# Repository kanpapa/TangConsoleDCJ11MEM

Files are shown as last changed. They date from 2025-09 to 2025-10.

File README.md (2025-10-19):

# TangConsoleDCJ11MEM
DEC DCJ11 processor test board using memory systems and peripherals implemented  on Tang Console 138K.

This document is written mostly in Japanese. If necessary, please use a translation service such as DeepL or Google.

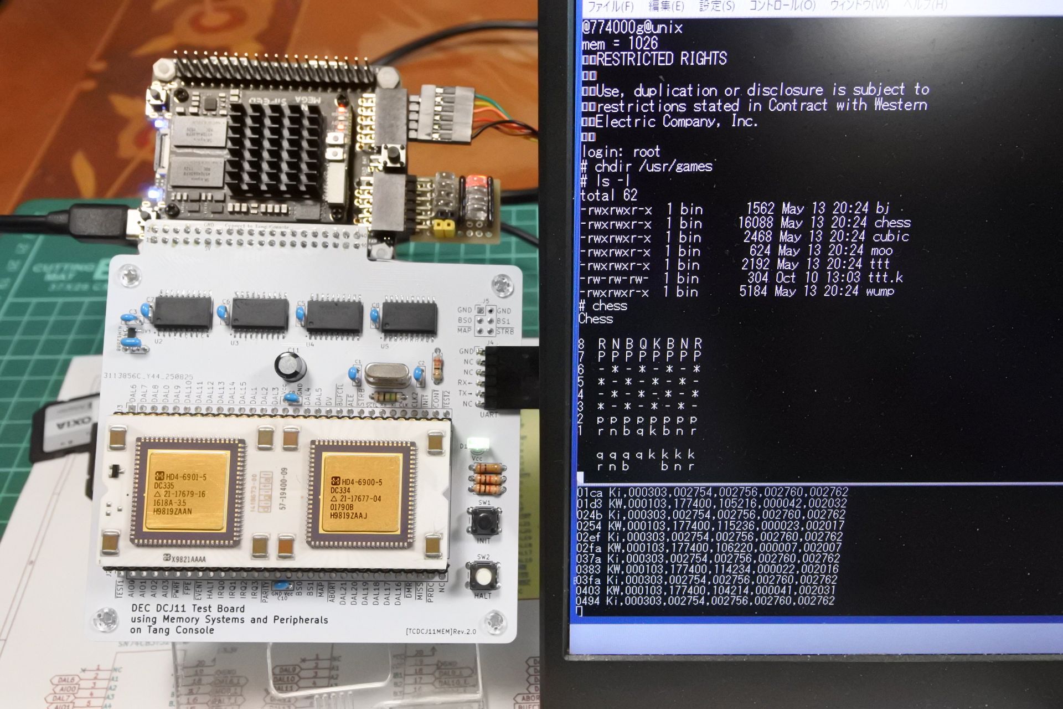
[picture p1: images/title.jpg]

# 概要
- PDP-11の命令セットを持つCPU「DEC DCJ11」のメモリシステムと周辺装置をFPGAボード(Tang Console 138K)上に実装する試みです．
- TangNano20Kを用いた同様のプロジェクト[TangNanoDCJ11MEM](https://github.com/ryomuk/TangNanoDCJ11MEM)の続編です．

各種説明は[doc/](./doc/)にあるファイルに記載しています．

## 最近の話題
- 以前の話題は[更新ログ](doc/01_updatelog.md)参照
- 2025/10/17
  - 磁気テープリーダ(TM11)等を実装してunix v7や2.9BSDをインストール可能なバージョン(20251017)を公開しました．わりと大幅なアップデートです．
  - ブートローダーのアドレスを実物のROM(BM873-YA)に準拠させるように変更しました．主なアドレスは下記のようになっています．詳細は[doc/06-1-bootloader.md](doc/06-1_bootloader.md)を参照して下さい．
    - RK(unix v1): 773700
    - RP(unix v6, RT-11等): 773010
  - 説明文書を[doc/](./doc/)にまとめました．まだログファイルそのままだったりソースのコメントのコピペばかりですが，動かすのに必要な情報は揃っていると思います．気が向いたらもう少し書き直します．

## 主要なファイル一覧
```
.
├── diskimage : SDメモリ用データ
│   ├── Caldera-license.pdf : UNIXのライセンス条項
│   ├── sd-unix-v1.dsk      : unix v1用disk image
│   └── sd-unix-v6.dsk      : unix v6用disk image
├── doc                      : 説明用文書
│   ├── 01_updatelog.md
│   ├── 02_PCB.md
│   ├── 03_FPGA.md
│   ├── 04_Interface.md
│   ├── 05_SDmemory.md
│   ├── 06-0_applications.md
│   ├── 06-1_bootloader.md
│   ├── 06-2_papertapebasic.md
│   ├── 06-3_unix-v1.md
│   ├── 06-4_unix-v6.md
│   ├── 06-5_unix-v7.md
│   ├── 06_6_unix-2.9BSD.md
│   ├── 06_7_RT-11v4.md
│   ├── 07_debugtool
│   └── 08_references.md
├── hdl                      : Gowin EDA用プロジェクト
│   ├── old                 : 旧版のバックアップ(あれば)
│   └── TangConsoleDCJ11MEM_project.xxxxxxxx
│       └── src
│             ├── rom.v      : ブートローダー
│             ├── sdhd.v     : HDエミュレータモジュール
│             ├── sdtape.v   : 紙テープエミュレータモジュール
│             ├── tc138k.cst : 物理制約(ピンアサイン)
│             ├── top.v      : メインプログラム
│             ├── uart.v     : uartモジュール
│             └── ws2812.v   : WS2812モジュール
├── images                    : 文書用画像ファイル
├── pcb
│   └── rev2.0 : 回路図，基板データ等(KiCAD 8用)
└── README.md
```
- diskimageフォルダ内にあるSDメモリ用のイメージファイルはUNIXのオリジナルソースからの派生物なので，ライセンス条件は Caldera-license.pdf (昔のBSD?)に従います．
- その他の部分についてはMITライセンスです．

## 動作状況
- unix v1
  - multi userで起動，rootでログインできました．
  - edでASCIIARTのプログラムを書いてccでセルフコンパイルして実行できました．
- unix v6
  - multi userで起動，rootでログインできました．
  - /usr/games/ にあるchessやbj, tttなどが動きました．
  - 実機でカーネルの再構築ができました．
- paper tape
  - paper tape BASICが起動して簡単なプログラムが動作しました．
  - unix v1, unix v6のデバイスとして読むことができました．
- rt-11 v4
  - 起動してHELP, DIRが動きました．(top.vのオプションを変更してビルドする必要あり)
- unix v7  
  - ディストリビューションテープからインストールとブートができました．
- 2.9BSD
  - ディストリビューションテープからインストールとブートができました．
  
## 既知の問題
- まれに(電源投入直後が多い)v6のブート時にpanicになって止まることがあります．
Tang Console のreconfigボタン(pmodコネクタのあたりにあるやつ)を押してリセットしてからリトライすると直ることが多いです．
- v6のファイルシステムは壊れやすいような気がします．電源断前にはsync3〜4回のおまじないが必要かも．
- v7でハードディスクにddしたbootloaderがちゃんと動かないような気がします．tapeのブートローダーでブートできます．

## 開発環境
- Windows 11
  - KiCAD 8.0.5
  - GOWIN FPGA Designer V1.9.11.02(64-bit)
  - VMware Workstation 17 Player
    - Ubuntu 22.04.4
      - dd
      - simh
  - TeraTerm
  - PDP11GUI

# 動画
- [UNIX V6 on DEC DCJ-11 (PDP-11) with Tang Console 138K](https://www.youtube.com/watch?v=6rK0t8tJp9Y)

# 更新履歴
- 2025/09/03: 初版(20250922)公開
- 2025/09/06: unix v6でもccが動いたのでREADME修正．
- 2025/09/08: READMEに軽微な情報追加．
- 2025/09/22: 20250922版(pmod paper tape実装)暫定公開．(説明は未)
- 2025/09/26: 20250926版公開．(RT-11 v4起動)
- 2025/10/19: 20251017版公開．(磁気テープ実装, unix v7, 2.9BSD起動)
- 2025/10/19: ドキュメント構成見直し

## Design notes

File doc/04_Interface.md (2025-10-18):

# インターフェース
## Pmodコネクタ
- Tang ConsoleのPmod(上がPmod1, 下がPmod0)のピンアサインは下記の通りです。
```
Pmod1:
+-----+-----+--------+--------+--------+--------+
| 3V3 | GND |LED_RGB |   NC   |   NC   |   NC   |
+-----+-----+--------+--------+--------+--------+
| 3V3 | GND |   NC   |   NC   |   NC   | LOG_TX |
+-----+-----+--------+--------+--------+--------+
Pmod0:
+-----+-----+---------+---------+---------+---------+
| 3V3 | GND |  CLK    |MISO(D0) |MOSI(CMD)| ~CS(D3) |
+-----+-----+---------+---------+---------+---------+
| 3V3 | GND |   NC    |  ~DET   | NC(D2)  |  NC(D1) |
+-----+-----+---------+---------+---------+---------+
```
### Pmod1(LED_RBG)
- WS2812 LED array用の信号を出力しています．デバッグをするにあたりかなり役に立っています．見た目も格好いいのでお薦めです．
- 基本情報8個、詳細情報16個+16個、計40個のLEDアレイへの出力です。
- 8個のアレイを継げれば基本情報8個だけ表示します。
- 表示内容はtop.vを参照して下さい。

### Pmod1(LOG_TX)
- ディスクアクセス等の情報を出力しています．

### Pmod0
  - テープデバイス(PC, TM)をエミュレートするためのSDカードを搭載します．Digilentのピンアサイン準拠になっています．SipeedのSDカードインターフェースもv2であれば同じようです．

## SW1, SW2
Tang Consoleのオンボードスイッチ(SW1, SW2)
- SW1: LEDアレイの出力内容切り替え．詳細はtop.v参照．
- SW2: 今のところ(20251017)明確な用途では使用していません．下記の用途で使うことがありますが，バージョンによって異なります．
  - sdtape.vの書き込みバッファのフラッシュ
  - 磁気テープのEOFフラグ
- SW1, SW2同時押し: SDメモリモジュール，UARTのリセット
  - Reconfigボタンでリセットの方を使うのであまり使っていません．

## ターミナルソフト(TeraTerm, PDP11GUI)との接続
- TTY入出力はTangConsoleのUSB(JTAGと共用)とCPU基板のUARTの2箇所に同じものが出ています．当初USBが不安定だったのでそのようにしたのですが，今はわりと安定してきたのでUSBだけでOKです．(両方使うとTeraTermとPDP11GUIを同時に接続できます．)
- TeraTermの設定
  - 基本的には115200bps,8N1N．ただし，UNIX V6だと7bit, parity=spaceにする必要あり．
  - 改行コードは入力出力ともCR
  - 送信遅延 10ms/字, 100ms/行
- CPU基板のUARTは，TXは3.3V出力(5VTTLで受信可)，RXは5V耐性なので，USBシリアル変換ケーブルは3.3V用，5V用のどちらでもOKです．

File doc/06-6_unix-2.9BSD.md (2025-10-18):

# 2.9BSD
- CPUタイプが70と認識されるのですが、それだとbootしてくれませんでした。CPUタイプを40とすればbootしたのでそれで対処しました。
## ディストリビューションテープからのインストール
- [https://www.tuhs.org/Archive/Distributions/UCB/2.9BSD/](https://www.tuhs.org/Archive/Distributions/UCB/2.9BSD/)にあるfile?.gz と usr.tar.gz をgunzipして，下記の配置でsdメモリに書き込み，PmodのSDメモリに搭載します．
```
dd if=file1 of=29bsdtape.dsk
dd if=file2 of=29bsdtape.dsk seek=65536 conv=notrunc
dd if=file3 of=29bsdtape.dsk seek=131072 conv=notrunc
dd if=file4 of=29bsdtape.dsk seek=196608 conv=notrunc
dd if=file5 of=29bsdtape.dsk seek=262144 conv=notrunc
dd if=file6 of=29bsdtape.dsk seek=327680 conv=notrunc
dd if=file7 of=29bsdtape.dsk seek=393216 conv=notrunc
dd if=usr.tar of=29bsdtape.dsk seek=458752 conv=notrunc

dd if=29bsdtape.dsk of=/dev/xxx
```
- Tang Consoleには空のSDメモリ(HDD用)を搭載します．
- https://www.tuhs.org/Archive/Distributions/UCB/Documentation/2.9bsd_setup.html の手順に従ってインストールします．
- 100040gで777570(switch register)に40を書き込みます。(ODTで手動で書き込んでもOK。)
- rom.vにより，100000番地以降にテープ用のブートローダーが書かれているのでODTで100000gで0番地に読み込まれます．これを0gで実行します．
```
@100040g
100050
@777570/000040 
@100000g
100014
@0
40Boot
: tm(0,3)
Mkfs
file system: rp(0,0)
file sys size: 5200
interleaving factor (m; 5 default): 
interleaving modulus (n; 10 default): 
isize = 3328
m/n = 5 10
Exit called

40Boot
: tm(0,4)
Restor
Tape? tm(0,6)
Disk? rp(0,0)
Last chance before scribbling on disk. 
End of tape
*** 数分かかる ***
40Boot
: rp(0,0)rpunix

Berkeley UNIX (Rev. 2.9.1) Sun Nov 20 14:55:50 PST 1983
mem = 135872

CONFIGURE SYSTEM:
xp ? csr 176700 vector 254 interrupt vector already in use
rk 0 csr 177400 vector 220 attached
hk ? csr 177440 vector 210 didn't interrupt
rl ? csr 174400 vector 160 didn't interrupt
rp ? csr 176700 vector 254 didn't interrupt
ht 0 csr 172440 vector 224 skipped:  No CSR
tm 0 csr 172520 vector 224 attached
ts 0 csr 172520 vector 224 interrupt vector already in use
dh ? csr 160020 vector 370 skipped:  No CSR
dm ? csr 170500 vector 360 skipped:  No autoconfig routines
dz ? csr 160110 vector 320 didn't interrupt
dz ? csr 160110 vector 320 didn't interrupt
dn 0 csr 175200 vector 300 skipped:  No autoconfig routines
vp ? csr 177500 vector 174 skipped:  No autoconfig routines
lp ? csr 177514 vector 200 didn't interrupt
Erase=^?, kill=^U, intr=^C
# dd if=/mdec/rpuboot of=/dev/rrp0a count=1
0+1 records in
0+1 records out
# cd /dev
# ./MAKE tm0
# ./MAKE rp1a rp1b rp1c rp1h
# ls rp*
rp0a  rp0b  rp0c  rp0h  rp1a  rp1b  rp1c  rp1h
# ls rrp*
rrp0a  rrp0b  rrp0c  rrp0h  rrp1a  rrp1b  rrp1c  rrp1h
# /etc/mkfs /dev/rrp1h 41590
isize = 26608
m/n = 5 10
# fsck /dev/rp0a

/dev/rp0a
File System: /

** Checking /dev/rp0a
** Phase 1 - Check Blocks and Sizes
** Phase 2 - Check Pathnames
** Phase 3 - Check Connectivity
** Phase 4 - Check Reference Counts
** Phase 5 - Check Free List 
250 files 1916 blocks 3074 free
# fsck /dev/rp1h

/dev/rp1h
File System: 

NEED SCRATCH FILE (65 BLKS)
ENTER FILENAME:  hoge
** Checking /dev/rp1h
** Phase 1 - Check Blocks and Sizes
** Phase 2 - Check Pathnames
** Phase 3 - Check Connectivity
** Phase 4 - Check Reference Counts
** Phase 5 - Check Free List 
3 files 6 blocks 39919 free
# /etc/mount /dev/rp1h /usr
# cd /usr
# df .
Filesystem  Mounted on  kbytes    used    free  % used
/dev/rp1h   /usr         39925       6   39919      0%
# mt -t /dev/nrmt0 fsf 7
# tar xvpf /dev/rmt0
Tar: blocksize = 20
x ./70/adb, 28204 bytes, 56 tape blocks
x ./70/make, 18182 bytes, 36 tape blocks
x ./70/dump, 9806 bytes, 20 tape blocks

*** 1時間ぐらいかかる ***

x ./ingres/version, 92 bytes, 1 tape blocks
x ./ingres/.cshrc, 64 bytes, 1 tape blocks
x ./ingres/.login, 158 bytes, 1 tape blocks
x ./ingres/.exrc, 27 bytes, 1 tape blocks
# ls
70          dict        ingres      man         public      tmp
adm         doc         lib         msgs        spool       ucb
bin         games       local       net         src
contrib     include     lost+found  preserve    sys
# ls bin
512dumpdir  dc          look        prep        sh          uuencode
512restor   delrem      lookbib     prfile      spell       uulog
Mail        deroff      lorder      primes      split       uuname
ac          diff3       ls          printenv    struct      uusend
at          dumpdir     m4          prof        sum         uusnap
awk         egrep       mesg        ptx         sync        uustat
basename    enroll      mkdir       px          tabs        uux
bc          eqn         neqn        pxp         tbl         why
cal         f77         nohup       quot        tp          write
calendar    factor      nroff       ratfor      tr          xget
cb          find        ovadb       refer       troff       xsend
checkeq     join        pcc         remind      tsort       yacc
checkobj    learn       pi          restor      tty
col         lex         pix         rev         unifdef
comm        lint        plot        sa          uniq
crypt       login       pr          sed         uudecode
```

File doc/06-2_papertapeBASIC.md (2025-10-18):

# Paper Tape BASIC
- PmodのSDメモリを使ってPaper TapeBASICが起動できます．
  - Tang ConsoleのSDスロットではなく、PmodにSDメモリインターフェースを接続して使用します。
- SDメモリの先頭から0〜1GBを読み込み用，1GB〜2GBを書き込み用にしたので，SAVEコマンドも動かそうと思えば動かせます．(が、最新版のtop.vではSAVE後にSW2でバッファをフラッシュの機能が外されてるかもしれないので修正が必要です。)

## 使用方法

- [Paper Tape Archive](https://www.vaxhaven.com/Paper_Tape_Archive)から
absolute loader('ABSOLUTE-BINARY-LOADER.ptap')と，Paper Tape BASIC ('DEC-11-AJPB-PB.ptap')を入手し，sdメモリに書き込みます．(頭の000があると読めないようで，先頭の16byteを削除しました．)
- /dev/xxx は生のsdメモリの場所です．(先頭のブロックから書くので数字が付いてないやつ．'fdisk -l'等で調べて下さい．)
- 間違えるとパソコンの他のファイルシステムを破壊するので厳重に注意して行って下さい．

```
cat ABSOLUTE-BINARY-LOADER.ptap DEC-11-AJPB-PB.ptap | dd of=tapeimage.dat bs=1 skip=16
dd if=tapeimage.dat of=/dev/xxx
```
- PmodのSDメモリカードに入れて電源を入れ，ODT consoleから下記のように
してBASICが起動できます．

```
@157744g  ← bootstrap loaderを起動してabsolute loaderを読み込む
157500
@157500g  ← absolute loaderを起動してBASICを読み込む
PDP-11 BASIC, VERSION 007A
*O ?
DO YOU NEED THE EXTENDED FUNCTIONS?Y
HIGH-SPEED READER/PUNCH?N
SET UP THE EXTERNAL FUNCTION?N
MEMORY?56
READY
10 PRINT "HELLO WORLD"
LIST

10 PRINT "HELLO WORLD"
READY
RUN
HELLO WORLD

STOP AT LINE   10
READY
```

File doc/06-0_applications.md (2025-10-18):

# 応用例

## [ブートローダー](06-1_bootloader.md)
## [Paper Tape BASIC](06-2_papertapeBASIC.md)
## [Unix v1](06-3_unix-v1.md)
## [Unix v6](06-4_unix-v6.md)
## [Unix v7](06-5_unix-v7.md)
## [2.9BSD Unix](06-6_unix-2.9BSD.md)
## [RT-11 v4](06-7_RT-11v4.md)

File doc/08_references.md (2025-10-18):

# 関連情報
## データシート等
### bitsavers
- [DCJ11 Microprocessor User's Guide](http://www.bitsavers.org/pdf/dec/pdp11/1173/EK-DCJ11-UG-PRE_J11ug_Oct83.pdf), DEC, EK-DCJ11-UG-PRE(Preliminary)
- [Index of /pdf/dec/pdp11/j11](http://bitsavers.trailing-edge.com/pdf/dec/pdp11/j11/)
- [Index of /pdf/dec/pdp11/1173](http://bitsavers.trailing-edge.com/pdf/dec/pdp11/1173/)

## 先行事例，先駆者たち
- [PDP-11/HACK](http://madrona.ca/e/pdp11hack/index.html), Brent Hilpert
- [My PDP-11 Projects](https://www.5volts.ch/pages/pdp11hack/), Peter Schranz
- [PDP11 on a breadboard A.K.A. J11 Hack](https://www.chronworks.com/J11/), Len Bayles
- [S100 Bus PDP-11 CPU Board](http://www.s100computers.com/My%20System%20Pages/PDP11%20Board/PDP11%20Board.htm), John Monahan

## 開発環境関連
- [PDP-11(エミュ）上でCで"Hello, World!"](https://qiita.com/hifistar/items/8eff4a73087f3a41e19f), hifistar
- [PDP-11のgccクロスコンパイル環境の構築メモ](https://qiita.com/hifistar/items/187fd7ad780c6aa26141), hifistar
- [SimH (History Simulator)](http://simh.trailing-edge.com/)
- [j-hoppe/PDP11GUI](https://github.com/j-hoppe/PDP11GUI)

## Paper Tape Software関連
- [Paper Tape Archive](https://www.vaxhaven.com/Paper_Tape_Archive)
- [DEC PDP-11 Paper Tape Images](https://www.pcjs.org/software/dec/pdp11/tapes/)
- [PDP-11 Paper Tape BASIC](https://avitech.com.au/?page_id=709)
- [Learning PDP-11](https://www.learningpdp11.com/) Paper Tape BASICとboot loaderについてとても詳しく解説されています

## UNIX関連
- [The Unix Heritage Society](https://www.tuhs.org/)
- [V1](https://www.tuhs.org/cgi-bin/utree.pl?file=V1)
- [UNIX First Edition](https://gunkies.org/wiki/UNIX_First_Edition)
- [jserv/unix-v1](https://github.com/jserv/unix-v1)

## 関連記事
- [きょうのかんぱぱ](https://kanpapa.com/today/)
TangNanoDCJ11MEMを使って私がやっていないようなことまでやっていたり，ここのREADMEより詳しく解説されてたりします．
  - [TangNanoDCJ11MEMでPDP-11のCPUを動かしてみました 製作編](https://kanpapa.com/today/2024/07/pdp-11-dcj11-cpu-1.html), 
  - [TangNanoDCJ11MEMでPDP-11のCPUを動かしてみました bare metal編](https://kanpapa.com/today/2024/07/tangnanodcj11mem-pdp-11-cpu-2-bare-metal.html)
  - [TangNanoDCJ11MEMとPDP11GUIでPDP-11 BASICを動かしてみました](https://kanpapa.com/today/2024/08/tangnanodcj11mem-pdp-11-cpu-3-pdp11basic.html)
  - [PDP-11 DCJ11 CPUでUNIX v6を動かしてみました](https://kanpapa.com/today/2024/08/tangnanodcj11mem-pdp-11-cpu-4-unix-v6.html)
  - [PDP-11 DCJ11 CPUでMINI-UNIXを動かしてみました](https://kanpapa.com/today/2024/08/tangnanodcj11mem-pdp-11-dcj11-cpu-mini-unix.html)

## その他のDCJ-11関連のプロジェクト
- ushicow, [PDP-11 Card for Apple II の制作](https://note.com/ushicow/m/ma9f73d2251bc)
- VARIABITS LAB, [DCJ11](https://www.variabits.com/categories/dcj11/)

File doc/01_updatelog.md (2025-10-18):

# 更新ログ
- 2025/09/12
  - PmodにWS2812アレイを接続してアドレスやデータを表示させてみました．
- 2025/09/22
  - PmodのSDメモリに紙テープエミュレータを実装しました．tape BASICの実行や，unix v1, v6で読めます．
- 2025/09/25
  - RT-11 v4がブートできました．
- 2025/09/26
  - READMEにpmod端子，オンボードSWの説明を追加しました．

- top.vにある更新履歴のコメント
```
//---------------------------------------------------------------------------
// 2025/09/02: - Ported from Tang Nano 20K to Tang Console 138K
//             - Use CLK2 as a system clock
//             - Physical memory space extended from 16bit to 18bit
//
// 2025/09/07: - Some debug tool installed
// 2025/09/11: - WS2812 installed
// 2025/09/17: - Bugfix for using without SD memory
// 2025/09/19: - PC-11(Paper-Tape Reader/Punch) emulator implemented
//             - The punch function is disabled to prevent overwriting
//             - the SD card.
// 2025/09/22: - sw2_toggle and sw2_count installed for debug
// 2025/09/25: - Onboard sw's function changed
// 2025/09/26: - Invoke IRQ_ttyo at 60Hz (dirty workaround to boot RT-11)
// 2025/10/01: - Bugfix for disks
// 2025/10/02: - RP11 controller (with RP03) emulator implemented
// 2025/10/06: - TM11/TU10 magnetic tape emulator implemented
//             - Reset by GP (RESET instruction)  implemented
//             - Boot address changed (see rom.v)
// 2025/10/08: - Disk and magtape bugfix
// 2025/10/12: - SD_MEM_FRQ changed from 400kHz to 800kHz
//             - Make read MTSC1(772440) invoke bus error (for uv7 tape boot)
// 2025/10/13: - TM11: Space forward implemented
// 2025/10/14: - TM11: interrupt on 'write IE and no GO' implemented
// 2025/10/16: - Image size for RP03 changed (for 2.9BSD's sys/conf/ioconf.c)
//             - RT-11 causes MTSC1 buserror, so compile flag
//             - 'USE_RT11V4_WORKAROUND' added.
//             - '60Hz IRQ_ttyo' disabled, 'USE_RT11V4_WORKAROUND' enables it.
//             - Compile flag 'USE_MT_WRITE_PROTECT' to avoid overwrite tape
// 2025/10/17: - SD_MEM_FRQ changed from 800kHz to 1MHz
//---------------------------------------------------------------------------
```

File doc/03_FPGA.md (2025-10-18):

# ビルド時の注意点
## config
- Configurationのdual-purpose pinで，SSPI, READY, DONE, CPUをチェックします．
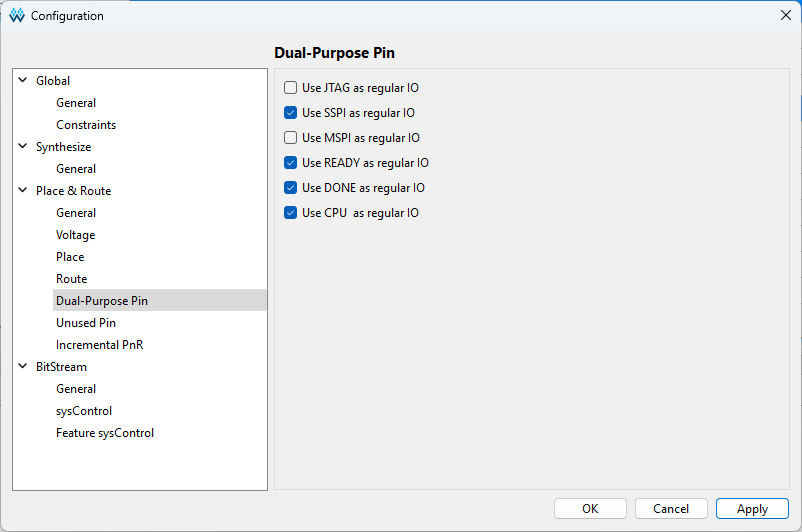
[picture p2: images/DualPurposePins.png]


## program
- UARTのポートが複数あるので，Gowin programmerでは適切なポートを選択する必要があります．
![ここに画像追加予定]()
- SRAMではなくflashメモリに書き込みます．数分かかります．
![ここに画像追加予定]()

## reconfigボタン
- Tang Consoleになって付いたreocnfigボタンがかなり便利です．FPGAをreconfigして初期化してくれます．Tang Nano 20Kのときには付いていなかった(それ用のパッドはある)ので毎回書き込み直していました．
![ここに画像追加予定]()

# FPGAに実装した機能
- コンソール入出力用UART
- Initialization Sequence時のPower-Up Configuration Register設定
- メモリ
  - 256KB RAM (760000-777777はI/O空間とROM用なので使えるのは248KB)
  - ブート用ROM
- ハードディスクドライブ RF11, RK11 (sdメモリによるエミュレーション)
- 外部演算装置 KE11-A (unix v1に必須)
- 紙テープリーダパンチャ PC11
- クロック KW11-L
- BS0, BS1は見ていません．DAL[15:0]とAIO[3:0]を見ればとりあえず十分だったので．
- DAL[21:18]も見ていません．
- 磁気テープドライブ TM11 (TU10)
- 大容量ハードディスクドライブRP11 (RP03)

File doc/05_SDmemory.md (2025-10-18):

## SDメモリ
- Tang Console本体のSDメモリスロットはHDDエミュレータ用です。
- PmodのSDカードインターフェース(ピン配置はDigilent仕様)のSDメモリは紙テープエミュレータと磁気テープエミュレータ用です。

## メモリイメージの構成
基本的にはtop.vのコメントに書いてあります．最新情報はソースを確認して下さい．
### ハードディスク
```
//---------------------------------------------------------------------------
// RF11 (drum), RK11 (disk), RP11 (with RP03 disk pack) controllers
// and TM11 (magtape)
// RF:  1024 block                             ( 512KB x 1)
// RK:  6144 block (=256cyl *  2sur *12sect)
//     (4872 block)(=203cyl *  2sur *12sect) (2.4 MB x 8)
// RP: 84000 block (=420cyl * 20tra *10sect)
//     (81200-83000 block) (=406-416cyl * 20tra *10sect) (40MB x 4)
// RP03's cylinder is 406, but 2.9BSD says 416.
//
// 1 block = 256word = 512B = 01000B
// SD memory block
//        0-  1023: RF  (00000000)
//     1024-  7167: RK0 (00002000)
//     7168- 13311: RK1 (00016000)
//    13312- 19455: RK2 (00032000)
//    19456- 25599: RK3 (00046000)
//    25600- 31742: RK4 (00062000)
//    31744- 37887: RK5 (00076000)
//    37888- 44031: RK6 (00112000)
//    44032- 50175: RK7 (00126000)
//    50176-134175: RP0 (00142000)
//   134176-218175: RP1 (00406040)
//   218176-302175: RP2 (00652100)
//   302176-386175: RP3 (01116140)
//
// # sample for making a sd image from unix disk drive images
// dd if=rf0 of=sd.dsk bs=512
// (if no rf0 file,  dd if=/dev/zero of=sd.dsk bs=512 count=1024)
// dd if=rk0 of=sd.dsk seek=1024  conv=notrunc
// dd if=rk1 of=sd.dsk seek=7168  conv=notrunc
// dd if=rk2 of=sd.dsk seek=13312 conv=notrunc
// dd if=rk3 of=sd.dsk seek=19456 conv=notrunc
// ...
// dd if=rp0 of=sd.dsk seek=50176 conv=notrunc
// ...
//---------------------------------------------------------------------------

### 磁気テープ
//--------------------------------------------------------------------------
// TM11
// maximum file block = 65536 block = 32MB
//      0-  65535: file0 (00000000)
//  65536- 131071: file1 (00200000)
// 131072- 196607: file2 (00400000)
// 196608- 262143: file3 (00600000)
// 262144- 327679: file4 (01000000)
// 327680- 393215: file5 (01200000)
// 393216- 458751: file6 (01400000)
// 458752- 524287: file7 (01600000)
// ...
// 983040-1048575: file15 (03600000)
//
// # sample for making a sd image from unix disk drive images
// dd if=file0 of=sdtape.dsk
// dd if=file1 of=sdtape.dsk seek=65536 conv=notrunc
// dd if=file2 of=sdtape.dsk seek=131072 conv=notrunc
// dd if=file3 of=sdtape.dsk seek=196608 conv=notrunc
// dd if=file4 of=sdtape.dsk seek=262144 conv=notrunc
// dd if=file5 of=sdtape.dsk seek=327680 conv=notrunc
// dd if=file6 of=sdtape.dsk seek=393216 conv=notrunc
// dd if=file7 of=sdtape.dsk seek=458752 conv=notrunc
// ...
// -----------------------------------------------------------------------
```
### 紙テープ
- 0〜1GBが読み込み用、1GB〜2GBが書き込み用ですが、書き込み機能はtop.vに修正が必要かも。

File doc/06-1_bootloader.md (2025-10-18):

# ブートローダー
- 773xxxのアドレスはBM873-YA restart/loader に準拠しています．
- 100000: TM11/TU10(磁気テープリーダ)
- 157744: 紙テープ用ブートストラップ
- 具体的なコードはrom.vを参照して下さい．

```
//---------------------------------------------------------------
// This ROM contains several boot programs
// - Magnetic Tape boot loader to install unix
// - Unix v1 boot ROM
// - BM873-YA restart/loader
// - Bootstrap Loader for paper tape
//
// Boot program entry addresses
//
// 100 000: TM11
// 157 744: PC11 (load absolute loader)
// 773 000: RF11 (not for unix v1, use 773700)
// 773 010: RK11 (unix v6, RT-11)
// 773 050: TM11
// 773 100: RP11
// 773 312: PC11
// 773 700: Unix V1 (RF)
//---------------------------------------------------------------

# スイッチレジスタ
//---------------------------------------------------------------
// SWR (Console Switches Register, 777570)
//---------------------------------------------------------------
REG_SWR = 'o173700; // UNIX V1 multi user mode
//REG_SWR = 'o073700; // UNIX V1 single user mode
//REG_SWR = 'o173030; // UNIX V6 single user mode
```
## 2.9BSD用の設定
2.9BSDは起動時にCPUタイプを自動判別しているようなのですが，'70'として判別されるとブートに失敗するので強制的に'40'にして起動しています．
詳細は https://www.tuhs.org/Archive/Distributions/UCB/Documentation/2.9bsd_setup.html を参照して下さい．

- CPUタイプを強制的に設定するためにSWRを使用します．
- Class: PDP11s
  - 40: 23, 34, 34A, 40, 60
  - 45: 45, 55
  - 70: 44, 70
- いちいち書くのは面倒なので，下記にレジスタ値を変更してHALTするプログラムを置きました．
  - 100040: SWR=o'000040
  - 100050: SWR=o'000045
  - 100070: SWR=o'000070

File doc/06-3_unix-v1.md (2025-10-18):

# UNIX V1
## 使用方法
### SDメモリの準備
- [jserv/unix-v1](https://github.com/jserv/unix-v1) にあるsimh用のunix-v1環境一式をmakeし， images/rf0.dsk, images/rk0.dsk からsd用のイメージsd.dskを作り、sdメモリに書き込む。
- 参考手順は下記の通り。
  - /dev/xxx は生のsdメモリの場所です．(先頭のブロックから書くので数字が付いてないやつ(/dev/sdb など)．'fdisk -l'等で調べて下さい．) 間違えるとパソコンの他のファイルシステムを破壊するので厳重に注意して行って下さい．
```
git clone https://github.com/jserv/unix-v1.git
cd unix-v1
make
dd if=images/rf0.dsk of=sd.dsk
dd if=images/rk0.dsk of=sd.dsk bs=512 seek=1024
sudo dd if=sd.dsk of=/dev/xxx
```

### 起動方法
- SDメモリをTangConsoleのスロットにセットします．
- 773700gでブートローダーを起動します．
- loginプロンプトが出るのでrootでログインします．
```
@773700g
login: root
root
# who
root    tty8 Jan  1 00:03:47
# date
Fri Jan  1 00:03:50
# chdir /tmp
# cc aa.c
I
II
# ls -l
total   14
127 sxrwrw  1 root   1062 Jan  1 00:00:00 a.out
121 s-rwrw  1 root    651 Jan  1 00:00:00 aa.c
129 s-rwrw  1 root   1104 Jan  1 00:00:00 aa.o
 55 sxrwrw  1 root   1664 Jan  1 00:00:00 etma
 56 sxrwrw  1 root     26 Jan  1 00:00:00 ttmp
 57 sxrwrw  1 root    142 Jan  1 00:00:00 utmp
# ./a.out

0000001111111111111111122222223333469 67433222221111111100000000000000000000000
000000011111111111111112222222334478  77933322222111111000000000000000000000000
0000000011111111111122222233243456B     944333221111111000000000000000000000000
0000000011111111211122222334556577A     965544422211110000000000000000000000000
00000111111111122222233333447 98         E 778532111111110000000000000000000000
00001111111122222232333344457                  43222111111000000000000000000000
000001111111122333444444455                  A643322111111000000000000000000000
000001111122223346666666667B                  A 4322111110000000000000000000000
000001222222333457F A  C889                    64322111111000000000000000000000
011111222223334458B      E                     93322111111111100000000000000000
01111222333444689E                             53322111111111100000000000000000
011122334555658                               643222221111111100000000000000000
011123                                       8543322211111111100000000000000000
011122334555658                               643222221111111100000000000000000
01111222333444689E                             53322111111111100000000000000000
011111222223334458B      E                     93322111111111100000000000000000
000001222222333457F A  C889                    64322111111000000000000000000000
000001111122223346666666667B                  A 4322111110000000000000000000000
000001111111122333444444455                  A643322111111000000000000000000000
00001111111122222232333344457                  43222111111000000000000000000000
00000111111111122222233333447 98         E 778532111111110000000000000000000000
0000000011111111211122222334556577A     965544422211110000000000000000000000000
0000000011111111111122222233243456B     944333221111111000000000000000000000000
000000011111111111111112222222334478  77933322222111111000000000000000000000000
0000001111111111111111122222223333469 67433222221111111100000000000000000000000
#
```

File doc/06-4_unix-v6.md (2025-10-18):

# UNIX V6

## お手軽な起動方法
- [diskimage/](../diskimage/)にあるsd-unix-v6.dskをSDメモリにddでを書き込み，TangConsoleのスロットにセットします．
- 773010gでブートローダーを起動するとすぐにプロンプト'@'が出るので，'unix'と入力します．
- loginプロンプトが出るのでrootでログインします．
```
@773010g@unix
mem = 1026
RESTRICTED RIGHTS

Use, duplication or disclosure is subject to
restrictions stated in Contract with Western
Electric Company, Inc.

login: root
# who
root    tty8 Oct 10 14:28
# date
Fri Oct 10 14:28:42 EDT 1975
```

## ディストリビューションテープからのインストール
- [https://www.tuhs.org/Archive/Distributions/Research/Ken_Wellsch_v6/](https://www.tuhs.org/Archive/Distributions/Research/Ken_Wellsch_v6/)にある v6.tape.gz をgunzipしてsdメモリに書き込み，PmodのSDメモリに搭載します．
```
gunzip v6.tape.gz
sudo dd if=v6.tape of=/dev/xxx
```
- Tang Consoleには空のSDメモリ(HDD用)を搭載します．
- https://www.tuhs.org/Archive/Distributions/Research/Documentation/v6_setup.html の手順に従ってインストールします．
- rom.vにより，100000番地以降にテープ用のブートローダーが書かれているのでODTで100000gで0番地に読み込まれます．これを0gで実行します．
```
?
@100000g
100014
@0g=tmrk
disk offset
0
tape offset
100
count
1
=tmrk
disk offset
1
tape offset
101
count
3999
=
137274
@773010g@rkunix
mem = 1035
RESTRICTED RIGHTS

Use, duplication or disclosure is subject to
restrictions stated in Contract with Western
Electric Company, Inc.

login: root
# chdir /usr/sys/conf
# ls
data.s
l.s
m40.s
m45.s
mkconf.c
sysfix
sysfix.c
# cc mkconf.c
# mv a.out mkconf
# ./mkconf
rk
rp
tm
done
# as m40.s
# mv a.out m40.o
# cc -c c.c
# as l.s
# ld -x a.out m40.o c.o ../lib1 ../lib2
# rm /unix
# mv a.out /unix
# 
# /etc/mknod /dev/rk0 b 0 0
# /etc/mknod /dev/rk1 b 0 1
# /etc/mknod /dev/rk2 b 0 2
# /etc/mknod /dev/rp0 b 1 0
# /etc/mknod /dev/mt0 b 3 0
# /etc/mknod /dev/rrk0 c 9 0
# /etc/mknod /dev/rrk1 c 9 1
# /etc/mknod /dev/rrk2 c 9 2
# /etc/mknod /dev/rrp0 c 11 0
# /etc/mknod /dev/rmt0 c 12 0
# sync
# sync
# sync
# 
002502
****リコンフィグボタンでリセット***
@773010g@unix
mem = 1035
RESTRICTED RIGHTS

Use, duplication or disclosure is subject to
restrictions stated in Contract with Western
Electric Company, Inc.

login: root
# dd if=/dev/mt0 of=/dev/rk1 count=4000 skip=4100
4000+0 records in
4000+0 records out
# dd if=/dev/mt0 of=/dev/rk2 count=4000 skip=8100
4000+0 records in
4000+0 records out
# mkdir /usr/doc
# cat >> /etc/rc
/etc/mount /dev/rk1 /usr/source
/etc/mount /dev/rk2 /usr/doc
# sync
# sync
# sync
# sync
# 
002506
@773010g@
000002
@
000002
@773010g@unix
mem = 1035
RESTRICTED RIGHTS

Use, duplication or disclosure is subject to
restrictions stated in Contract with Western
Electric Company, Inc.

login: root
# /etc/mkfs /dev/rp0 40600
isize = 489
free list 4/10
# mkdir /home
# cat >> /etc/rc
/etc/mount /dev/rp0 /home
# icheck /dev/rrp0
/dev/rrp0:
spcl       0
files      0
large      0
direc      1
indir      0
used       1
free   40108
# dcheck /dev/rrp0
/dev/rrp0:
# /etc/mount /dev/rp0 /home
# df /home
/home read error 1
count = 0; errno = 0
# ls /home
# df /dev/rp0
/dev/rp0 40108
# /etc/mount
rk1 on /usr/source
rk2 on /usr/doc
rp0 on /home
# ls /usr/source
as
c
cref
fort
iolib
m6
mdec
rat
run
s1
s2
s3
s4
s5
s7
salloc
sno
tmg
yacc
# ls -l /usr/source
total 36
drwxrwxr-x  2 bin       368 Jul 18 08:59 as
drwxrwxr-x  2 bin       928 Jul 18 09:04 c
drwxrwxr-x  5 bin       128 May 13 20:37 cref
drwxrwxr-x 11 bin       288 Jul 18 09:12 fort
drwxrwxr-x  2 bin      1248 Jul 18 09:16 iolib
drwxrwxr-x  2 bin       320 Jul 18 09:30 m6
drwxrwxr-x  2 bin       464 Jul 18 11:26 mdec
drwxrwxr-x  2 bin       256 Jul 18 09:32 rat
-rw-rw-r--  1 bin       753 May 18 13:50 run
drwxrwxr-x  2 bin      1696 Jul 18 11:33 s1
drwxrwxr-x  2 bin      1280 Jul 18 09:59 s2
drwxrwxr-x  2 bin       816 Jul 18 09:59 s3
drwxrwxr-x  2 bin      2544 Jul 18 10:01 s4
drwxrwxr-x  2 bin      1264 Jul 18 10:03 s5
drwxrwxr-x  2 bin       800 Jul 18 10:06 s7
drwxrwxr-x  2 bin       384 Jul 18 10:06 salloc
drwxrwxr-x  2 bin       224 Jul 18 10:07 sno
drwxrwxr-x  3 bin       176 Jul 18 10:09 tmg
drwxrwxr-x  4 bin        80 May 13 20:37 yacc
# ls -l /usr/doc
total 15
drwxrwxr-x  2 bin        48 Jun 26 20:05 as
drwxrwxr-x  2 bin        80 Jun 26 20:05 bc
drwxrwxr-x  2 bin       176 Jun 26 20:05 beg
drwxrwxr-x  2 bin       240 Jun 26 20:05 c
drwxrwxr-x  2 bin       464 Jun 26 20:05 ctut
drwxrwxr-x  2 bin       176 Jun 26 20:05 ed
drwxrwxr-x  2 bin       144 Jun 26 20:05 hel
drwxrwxr-x  2 bin        48 Jun 26 20:05 iolib
drwxrwxr-x  2 bin        48 Jun 26 20:05 iosys
drwxrwxr-x 11 bin       192 Jun 26 20:37 man
drwxrwxr-x  2 bin        48 Jun 26 20:05 rat
drwxrwxr-x  2 bin        64 Jun 26 20:05 secur
drwxrwxr-x  2 bin        96 Jul 17 12:28 start
drwxrwxr-x  2 bin       192 Jun 26 20:05 unix
drwxrwxr-x  2 bin       288 Jun 26 20:05 yacc
# sync
# sync
# sync
# 
```

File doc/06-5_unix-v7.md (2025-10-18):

# unix v7
## ディストリビューションテープからのインストール
- [https://www.tuhs.org/Archive/Distributions/Research/Keith_Bostic_v7/](https://www.tuhs.org/Archive/Distributions/Research/Keith_Bostic_v7/)にあるf?.gz をgunzipして，下記の配置でsdメモリに書き込み，PmodのSDメモリに搭載します．
```
dd if=f0 of=v7tape.dsk
dd if=f1 of=v7tape.dsk seek=65536 conv=notrunc
dd if=f2 of=v7tape.dsk seek=131072 conv=notrunc
dd if=f3 of=v7tape.dsk seek=196608 conv=notrunc
dd if=f4 of=v7tape.dsk seek=262144 conv=notrunc
dd if=f5 of=v7tape.dsk seek=327680 conv=notrunc
dd if=f6 of=v7tape.dsk seek=393216 conv=notrunc

dd if=v7tape.dsk of=/dev/xxx
```
- Tang Consoleには空のSDメモリ(HDD用)を搭載します．
- https://www.tuhs.org/Archive/Distributions/Research/Documentation/v7_setup.html の手順に従ってインストールします．
- rom.vにより，100000番地以降にテープ用のブートローダーが書かれているのでODTで100000gで0番地に読み込まれます．これを0gで実行します．
```
?
@100000g
100014
@0gBoot
: tm(0,3)
file sys size: 5000
file system: rp(0,0)
isize = 1600
m/n = 3 500
Exit called
Boot
: tm(0,3)
file sys size: 74000
file system: rp(0,7000)
isize = 23680
m/n = 3 500
Exit called
Boot
: tm(0,4)
Tape? tm(0,5)
Disk? rp(0,0)
Last chance before scribbling on disk. 
End of tape
Boot
: tm(0,4)
Tape? tm(0,6)
Disk? rp(0,7000)
Last chance before scribbling on disk. 
End of tape
Boot
: rp(0,0)rptmunix
No more file slots
Trap 30340

014676
@100000g
@0Boot
: rp(0,0)rptmunix
mem = 178624
# FSCK /DEV/RP0A
FSCK: NOT FOUND
# LS -L /DEV/
TOTAL 2
CRW--W--W- 1 ROOT    0,  0 DEC 31 19:00 CONSOLE
CRW-R--R-- 1 BIN     8,  1 JAN 10 15:40 KMEM
-RW-RW-R-- 1 BIN       775 JAN 10 15:26 MAKEFILE
CRW-R--R-- 1 BIN     8,  0 JAN 10 15:39 MEM
CRW-RW-RW- 1 BIN     8,  2 JAN 23 16:35 NULL
CRW-RW-RW- 1 BIN    17,  0 JAN 10 15:40 TTY
# CD DEV
# MAKE RP03
/ETC/MKNOD RP0 B 1 1
/ETC/MKNOD SWAP B 1 2
/ETC/MKNOD RP3 B 1 3
/ETC/MKNOD RRP0 C 11 1
/ETC/MKNOD RRP3 C 11 3
CHMOD GO-W RP0 SWAP RP3 RRP0 RRP3
# LS -L
TOTAL 2
CRW--W--W- 1 ROOT    0,  0 DEC 31 19:01 CONSOLE
CRW-R--R-- 1 BIN     8,  1 JAN 10 15:40 KMEM
-RW-RW-R-- 1 BIN       775 JAN 10 15:26 MAKEFILE
CRW-R--R-- 1 BIN     8,  0 JAN 10 15:39 MEM
CRW-RW-RW- 1 BIN     8,  2 JAN 23 16:35 NULL
BRW-R--R-- 1 ROOT    1,  1 DEC 31 19:00 RP0
BRW-R--R-- 1 ROOT    1,  3 DEC 31 19:00 RP3
CRW-R--R-- 1 ROOT   11,  1 DEC 31 19:00 RRP0
CRW-R--R-- 1 ROOT   11,  3 DEC 31 19:00 RRP3
BRW-R--R-- 1 ROOT    1,  2 DEC 31 19:00 SWAP
CRW-RW-RW- 1 BIN    17,  0 JAN 10 15:40 TTY
# MAKE TM
/ETC/MKNOD MT0 B 3 0
/ETC/MKNOD RMT0 C 12 0
/ETC/MKNOD NRMT0 C 12 128
CHMOD GO+W MT0 RMT0 NRMT0
# /ETC/MOUNT /DEV/RP3 /USR
# LS /USR/MDEC
HPUBOOT
HPUBOOT.S
MAKEFILE
RPUBOOT
RPUBOOT.S
# DD IF=/USR/MDEC/RPUBOOT OF=/DEV/RP0 COUNT=1
0+1 RECORDS IN
0+1 RECORDS OUT
# SYNC
# SYNC
# SYNC
# 
002306
@100000g
100014
@0Boot
: rp(0,0)rptmunix
mem = 178624
# /ETC/FSCK /DEV/RRP0
/ETC/FSCK: NOT FOUND
# FSCK /DEV/RRP0
FSCK: NOT FOUND
# /ETC/MOUNT /DEV/RP3 /USR
# LS USR/BIN
USR/BIN NOT FOUND
# LS USR
DICT
DMR
DOC
GAMES
INCLUDE
LIB
MAN
MDEC
PUB
SPOOL
SRC
SYS
TMP
# LS BIN
1
AC
ADB
AR
ARCV
AS
AT
AWK
BAS
BASENAME
BC
CAL
CALENDAR
CAT
CB
CC
CHECKEQ
CHGRP
CHMOD
CHOWN
CLRI
CMP
COL
COMM
CP
CRYPT
CU
DATE
DC
DCHECK
DD
DEROFF
DF
DIFF
DIFF3
DU
DUMP
DUMPDIR
ECHO
ED
EGREP
ENROLL
EQN
EXPR
F77
FACTOR
FALSE
FGREP
FILE
FIND
GRAPH
GREP
ICHECK
IOSTAT
JOIN
KILL
LD
LEARN
LEX
LINT
LN
LOGIN
LOOK
LOOKBIB
LORDER
LS
M4
MAIL
MAKE
MAN
MESG
MKDIR
MV
NCHECK
NEQN
NEWGRP
NICE
NM
NOHUP
NROFF
OD
OSH
PASSWD
PCC
PLOT
PR
PREP
PRIMES
PROF
PS
PSTAT
PTX
PWD
QUOT
RANDOM
RANLIB
RATFOR
REFER
RESTOR
REV
RM
RMDIR
ROFF
SA
SED
SH
SIZE
SLEEP
SORT
SP
SPELL
SPLINE
SPLIT
STRIP
STRUCT
STTY
SU
SUM
SYNC
T300
T300S
T450
TABS
TAIL
TAR
TBL
TC
TEE
TEK
TEST
TIME
TK
TOUCH
TP
TR
TROFF
TRUE
TSORT
TTY
UNIQ
UNITS
UUCP
UULOG
UUX
VPLOT
VPR
WC
WHO
WRITE
XGET
XSEND
YACC
YES
# LS /USR
DICT
DMR
DOC
GAMES
INCLUDE
LIB
MAN
MDEC
PUB
SPOOL
SRC
SYS
TMP
# LS -L /USR
TOTAL 15
DRWXRWXR-X 3 BIN       128 JAN 10 15:18 DICT
DRWXRWXR-X 2 DMR       400 MAY 16 15:37 DMR
DRWXRWXR-X21 BIN       688 JAN 20 05:57 DOC
DRWXRWXR-X 5 BIN       416 JAN 10 15:19 GAMES
DRWXRWXR-X 3 BIN       496 MAY  5 02:16 INCLUDE
DRWXRWXR-X10 BIN       544 MAY 15 23:38 LIB
DRWXRWXR-X11 BIN       176 JAN 10 15:17 MAN
DRWXRWXR-X 2 BIN       112 JAN 10 15:24 MDEC
DRWXRWXR-X 2 BIN        80 JAN 10 15:19 PUB
DRWXRWXR-X 6 BIN        96 MAY 11 02:50 SPOOL
DRWXRWXR-X12 BIN       208 JAN 22 18:57 SRC
DRWXRWXR-X 7 SYS       128 MAY 14 00:12 SYS
DRWXRWXRWX 2 BIN       224 MAY 16 15:28 TMP
# DF
/DEV/RP0 987
/DEV/RP3 54365
# SYNC
# SYNC
# SYNC
# SYNC
```

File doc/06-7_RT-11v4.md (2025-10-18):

# RT-11 version4

- 試行錯誤の末、若干のworkaroundを追加することによって起動させることができました。
- ちゃんと使うにはフロッピーディスクのエミュレーションが必要そうなのですが、プロトコルが面倒そうなのでまだ作っていません。

- top.vでコメントアウトされている下記の行を有効にしてビルドします。
```
`define USE_RT11V4_WORKAROUND  // uncomment this line to boot RT-11 v4
```
## sdメモリイメージ
- wfjm's Home[System Images](https://wfjm.github.io/home/w11/inst/systems.html)にある RT11 V4.0 rkset にある rtv4_rk.dsk から、下記の手順でsdメモリ用イメージを作ます。
```
dd if=/dev/zero of=sd-rtv4.dsk count=1024
dd if=rtv4_rk.dsk of=sd-rtv4.dsk seek=1024 conv=notrunc
```
- これをddでsdメモリの先頭に書き込みます。デバイス名はちゃんと調べて絶対に間違えないようにして下さい。間違えるとパソコンの記憶領域を破壊する可能性があります。
```
dd if=sd-rtv4.dsk of=/dev/xxx  ←xxxはsdメモリのデバイス名に直して下さい。
```

## 起動方法
```
@773010g
RT-11SJ  V04.00C 

.D 56=5015

.TYPE V4USER.TXT
Welcome to RT-11 Version 4. RT-11 V04 provides new hardware support
and some major enhancements over Version 3B.

Please use the HELP command;  it describes the new options in many
of the utilities.

If you are using a terminal that requires fill characters,
modify location 56 with a Deposit command before proceeding with
system installation. LA36 DECwriter II and VT52 DECscope terminals
do NOT require such modification.

.D 56=0

.DIR
 
SWAP  .SYS    25  01-Feb-82      RT11BL.SYS    65  01-Feb-82
RT11SJ.SYS    67  01-Feb-82      RT11FB.SYS    80  01-Feb-82
TT    .SYS     2  01-Feb-82      DT    .SYS     3  01-Feb-82
DP    .SYS     3  01-Feb-82      DX    .SYS     3  01-Feb-82
DY    .SYS     4  01-Feb-82      RF    .SYS     3  01-Feb-82
RK    .SYS     3  01-Feb-82      DL    .SYS     4  01-Feb-82
DM    .SYS     5  01-Feb-82      DS    .SYS     3  01-Feb-82
DD    .SYS     5  01-Feb-82      MT    .SYS     9  01-Feb-82
MM    .SYS     9  01-Feb-82      MS    .SYS    10  01-Feb-82
LP    .SYS     2  01-Feb-82      LS    .SYS     2  01-Feb-82
CR    .SYS     3  01-Feb-82      NL    .SYS     2  01-Feb-82
PC    .SYS     2  01-Feb-82      PD    .SYS     3  01-Feb-82
CT    .SYS     6  01-Feb-82      BA    .SYS     7  01-Feb-82
PIP   .SAV    23  01-Feb-82      DUP   .SAV    41  01-Feb-82
DIR   .SAV    17  01-Feb-82      FORMAT.SAV    19  01-Feb-82
SLP   .SAV     9  01-Feb-82      SIPP  .SAV    20  01-Feb-82
STARTS.COM     1  01-Feb-82      STARTF.COM     1  01-Feb-82
V4USER.TXT     1  01-Feb-82      CREF  .SAV     6  01-Feb-82
DUMP  .SAV     8  01-Feb-82      MBOT16.BOT     1  01-Feb-82
RESORC.SAV    15  01-Feb-82      SYSMAC.SML    42  01-Feb-82
EDIT  .SAV    19  01-Feb-82      KED   .SAV    60  01-Feb-82
K52   .SAV    55  01-Feb-82      TECO  .SAV    50  01-Feb-82
MACRO .SAV    51  01-Feb-82      MAC8K .SAV    56  01-Feb-82
LINK  .SAV    41  01-Feb-82      LIBR  .SAV    22  01-Feb-82
FILEX .SAV    18  01-Feb-82      SRCCOM.SAV    13  01-Feb-82
BINCOM.SAV    10  01-Feb-82      MTHD  .SYS     4  01-Feb-82
MMHD  .SYS     4  01-Feb-82      MSHD  .SYS     5  01-Feb-82
PATCH .SAV    10  01-Feb-82      PAT   .SAV     8  01-Feb-82
HELP  .SAV   107  01-Feb-82      HELP  .EXE     7  01-Feb-82
HELP  .MLB    98  01-Feb-82      ERROUT.SAV    17  01-Feb-82
SYSGEN.SAV    39  01-Feb-82      SYSGEN.CND   134  01-Feb-82
SYSTBL.CND    23  01-Feb-82      BATCH .SAV    26  01-Feb-82
QUEMAN.SAV    13  01-Feb-82      QUEUE .REL    14  01-Feb-82
SYSLIB.OBJ    47  01-Feb-82      MDUP  .SAV    18  01-Feb-82
MDUP  .MM     48  01-Feb-82      MDUP  .MT     48  01-Feb-82
MDUP  .MS     48  01-Feb-82      MBOOT .BOT     1  01-Feb-82
MSBOOT.BOT     3  01-Feb-82      DEMOF1.FOR     2  01-Feb-82
DEMOED.TXT     1  01-Feb-82      README.TXT    36  01-Feb-82
VT52  .TEC     5  01-Feb-82      VEG   .TEC     4  01-Feb-82
EDIT  .TEC     1  01-Feb-82      INSERT.TEC     2  01-Feb-82
LOCAL .TEC     3  01-Feb-82      SORT  .TEC     3  01-Feb-82
VTEDIT.TEC    32  01-Feb-82      TECO  .TC     23  01-Feb-82
SEARCH.TEC     3  01-Feb-82      SQU   .TEC    13  01-Feb-82
TYPE  .TEC    12  01-Feb-82      TECO  .INI    15  01-Feb-82
ODT   .OBJ     9  01-Feb-82      VDT   .OBJ     9  01-Feb-82
VTHDLR.OBJ     9  01-Feb-82      PLOT55.OBJ     3  01-Feb-82
TEST55.FOR     5  01-Feb-82      GETSTR.FOR     2  01-Feb-82
PUTSTR.FOR     2  01-Feb-82      SPEED .SAV     4  01-Feb-82
SYCND .BL      3  01-Feb-82      SYSTBL.BL      4  01-Feb-82
SYCND .DIS     5  01-Feb-82      SYCND .HD      5  01-Feb-82
SYSTBL.DIS     4  01-Feb-82      RTBL  .MAP    16  01-Feb-82
RTSJ  .MAP    16  01-Feb-82      RTFB  .MAP    23  01-Feb-82
DISMT1.COM     9  01-Feb-82      DISMT2.COM     8  01-Feb-82
 106 Files, 1942 Blocks
 2820 Free blocks

.
```

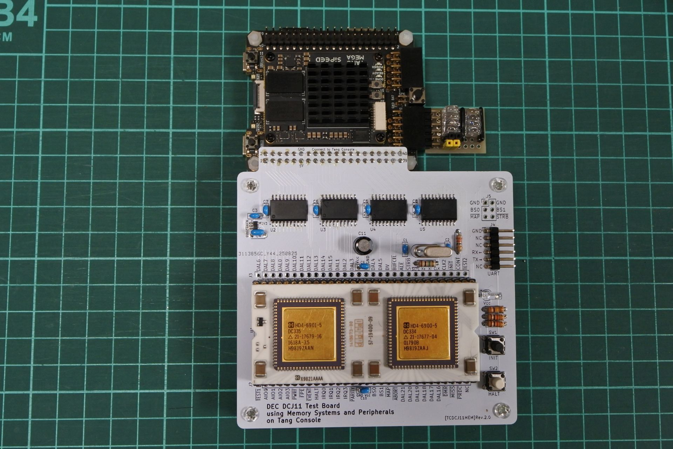
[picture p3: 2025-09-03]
images/rev20.jpg

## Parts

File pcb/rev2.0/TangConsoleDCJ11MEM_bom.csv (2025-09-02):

Source: | C:\wks\ework\KiCad\TangConsoleDCJ11MEM\rev2.0\TangConsoleDCJ11MEM.kicad_sch
Date: | 2025-09-02T14:45:00+0900
Tool: | Eeschema 8.0.5
Generator: | C:\Program Files\KiCad\8.0\bin\scripting\plugins/bom_csv_grouped_by_value_with_fp.py
Component Count: | 40
Ref | Qnty | Value | Cmp name | Footprint | Description | Vendor | DNP
C1, C2 | 2 | 68p | C | 000_MyFootprint:C_Disc_D5.0mm_W2.5mm_P2.50mm | Unpolarized capacitor
C3, C5, C6, C7, C8 | 5 | 0.1uF | C_Small | 000_MyFootprint:C_Disc_D5.0mm_W2.5mm_P2.50mm | Unpolarized capacitor, small symbol
C4 | 1 | 1uF | C_Small | 000_MyFootprint:C_Disc_D4.7mm_W2.5mm_P5.00mm | Unpolarized capacitor, small symbol
C9, C10 | 2 | 0.33uF | C | 000_MyFootprint:C_Disc_D5.0mm_W2.5mm_P2.50mm | Unpolarized capacitor
C11 | 1 | 47uF | C_Polarized | 000_MyFootprint:CP_Radial_D6.3mm_P2.50mm | Polarized capacitor
D1 | 1 | LED | LED | 000_MyFootprint:LED_D3.0mm | Light emitting diode
J1 | 1 | Conn_02x20_Odd_Even | Conn_02x20_Odd_Even | 000_MyFootprint:PinSocket_2x20_P2.54mm_Vertical | Generic connector, double row, 02x20, odd/even pin numbering scheme (row 1 odd numbers, row 2 even numbers), script generated (kicad-library-utils/schlib/autogen/connector/)
J2, J3 | 2 | Conn_01x30 | Conn_01x30 | 000_MyFootprint:PinSocket_1x30_P2.54mm_Vertical | Generic connector, single row, 01x30, script generated (kicad-library-utils/schlib/autogen/connector/)
J4 | 1 | UART | Conn_01x06_Pin | 000_MyFootprint:PinHeader_1x06_P2.54mm_Horizontal | Generic connector, single row, 01x06, script generated
J5 | 1 | EXT | Conn_02x03_Odd_Even | 000_MyFootprint:PinHeader_2x03_P2.54mm_Vertical | Generic connector, double row, 02x03, odd/even pin numbering scheme (row 1 odd numbers, row 2 even numbers), script generated (kicad-library-utils/schlib/autogen/connector/)
R1 | 1 | 1M | R | 000_MyFootprint:R_Axial_DIN0207_L6.3mm_D2.5mm_P7.62mm_Horizontal | Resistor
R2, R3, R4, R5, R6, R7, R8, R9, R10 | 9 | 10k | R | 000_MyFootprint:R_Axial_DIN0207_L6.3mm_D2.5mm_P7.62mm_Horizontal | Resistor
R11 | 1 | 33 | R | 000_MyFootprint:R_Axial_DIN0207_L6.3mm_D2.5mm_P7.62mm_Horizontal | Resistor
R12 | 1 | 100k | R | 000_MyFootprint:R_Axial_DIN0207_L6.3mm_D2.5mm_P7.62mm_Horizontal | Resistor
R13, R14 | 2 | 1k | R | 000_MyFootprint:R_Axial_DIN0207_L6.3mm_D2.5mm_P7.62mm_Horizontal | Resistor
SW1 | 1 | INIT | SW_Push | 000_MyFootprint:SW_PUSH_6mm_H4.3mm | Push button switch, generic, two pins
SW2 | 1 | HALT | SW_Push | 000_MyFootprint:SW_PUSH_6mm_H4.3mm | Push button switch, generic, two pins
U1 | 1 | DCJ11 | DCJ11 | 000_MyFootprint:DIP-60_W33.02mm_LongPads
U2, U3, U4, U5 | 4 | SN74CB3T3245DW | SN74CB3T3245DW | 000_MyFootprint:DW20
U6 | 1 | NJM12888F33-TE1 | NJM12888F33-TE1 | 000_MyFootprint:SOT-23-5_HandSoldering
Y1 | 1 | 18MHz | Crystal | 000_MyFootprint:Crystal_HC49-U_Vertical | Two pin crystal

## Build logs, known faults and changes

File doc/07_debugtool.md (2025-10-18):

# デバッグ機能
- デバッグ用の機能をいくつか実装しています．詳細はtop.vを見て下さい．
## disk accessログ

- top.vの `define USE_ACCESSLOG を有効にすると使えます．(無効化したことがないので無効化してちゃんとビルドできるかどうかは不明)
- GPIOのUARTにディスクアクセスに関する情報を出力しています．
  - 100μ秒のカウンタ，ディスク関連レジスタ，最後に読んだ命令のアドレスなどを表示しています．
## ブレークポイント
- デバッグ用レジスタDBG_REG0〜2(177100, 177102, 177104番地)に書いたアドレスの命令をフェッチしたときにHALT信号を出力する機能です．トリガ条件は下記の2種類があります．
  - (address == DBG_REG0 )
  - (address == DBG_REG1 ) の後に(address == DBG_REG2 )

## 命令ログ
  - 177000〜177056番地に，HALTする直前にフェッチしていた命令のアドレスを24個記録しています．原因不明のHALTが起きたときの解析用です．(プリフェッチしているので，実行ではなくフェッチです．時系列は177000→177056の順．バージョンによっては個数が違う場合あり．詳細はソース参照．)

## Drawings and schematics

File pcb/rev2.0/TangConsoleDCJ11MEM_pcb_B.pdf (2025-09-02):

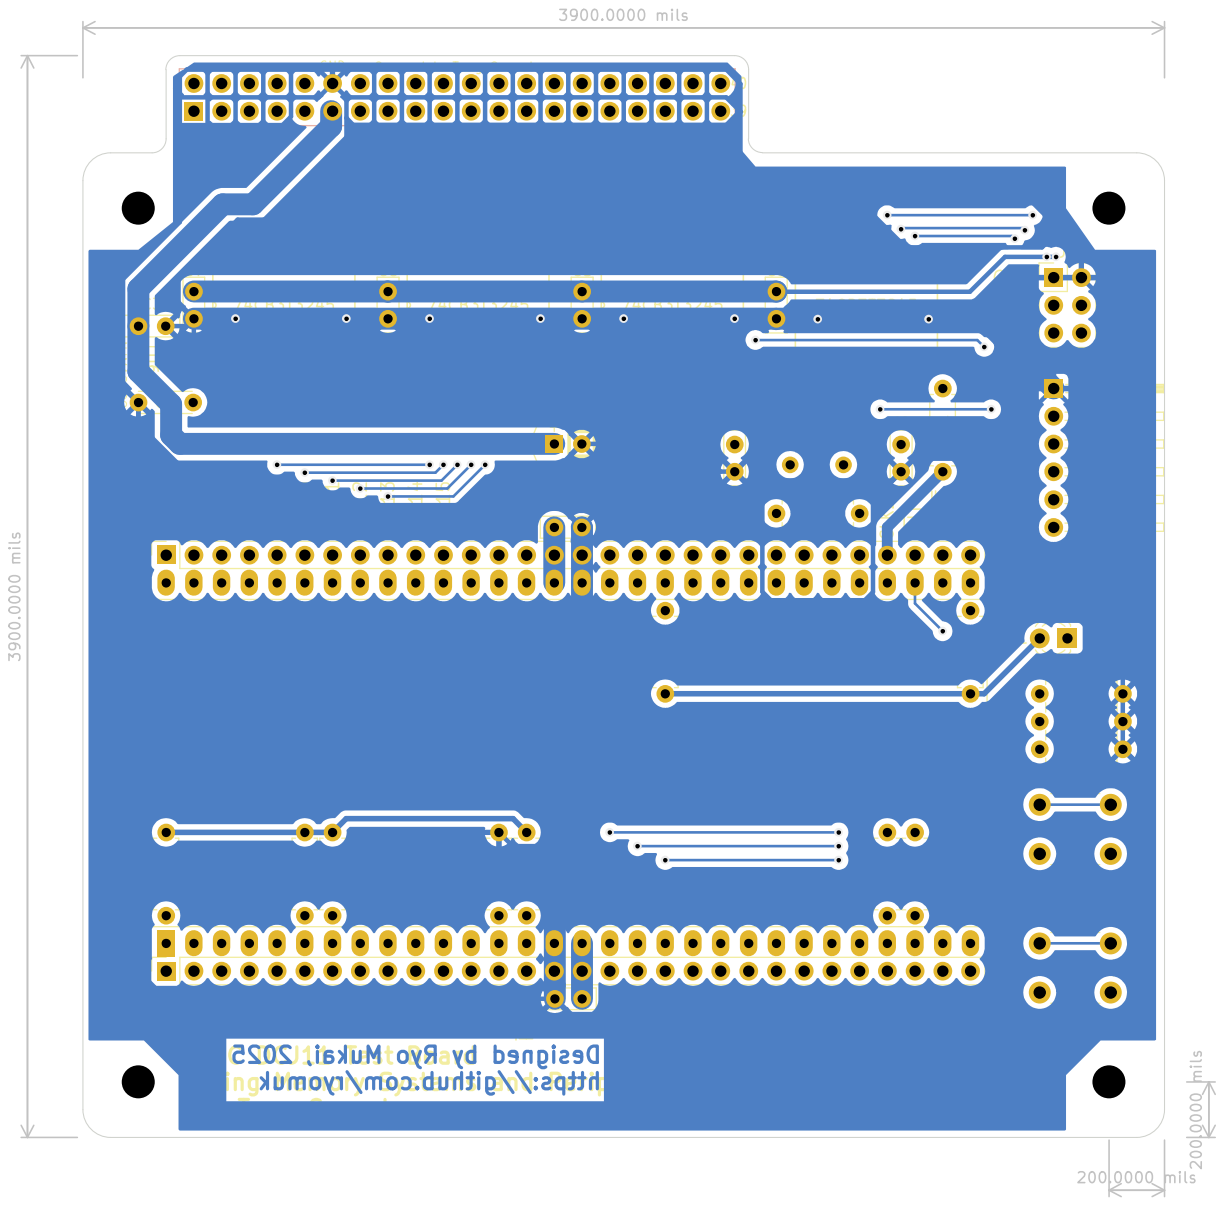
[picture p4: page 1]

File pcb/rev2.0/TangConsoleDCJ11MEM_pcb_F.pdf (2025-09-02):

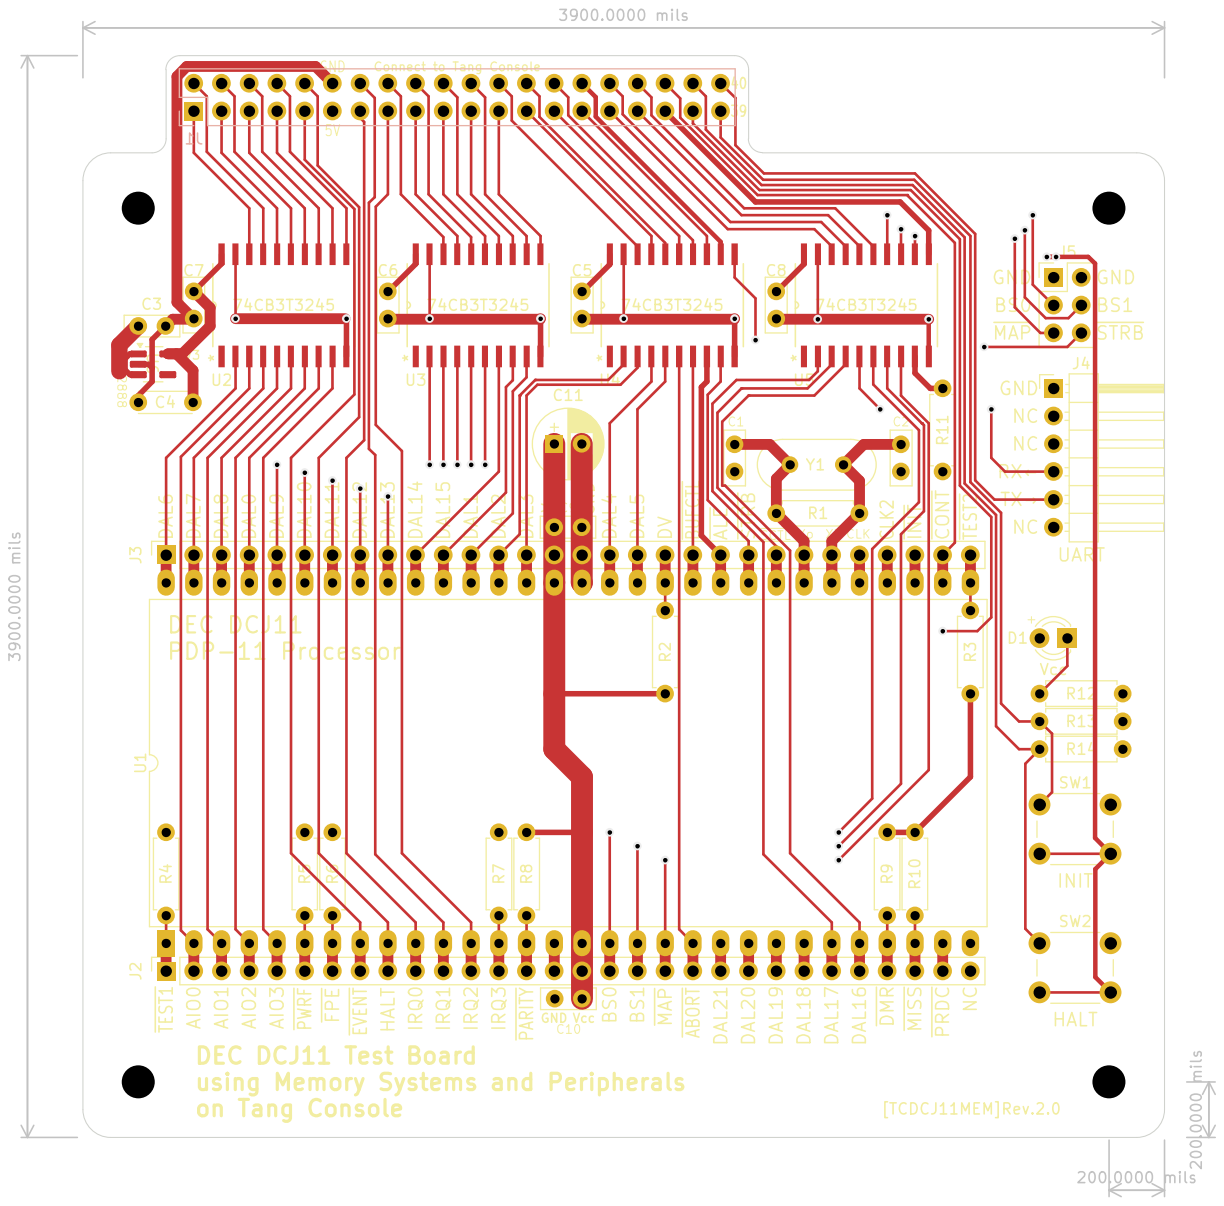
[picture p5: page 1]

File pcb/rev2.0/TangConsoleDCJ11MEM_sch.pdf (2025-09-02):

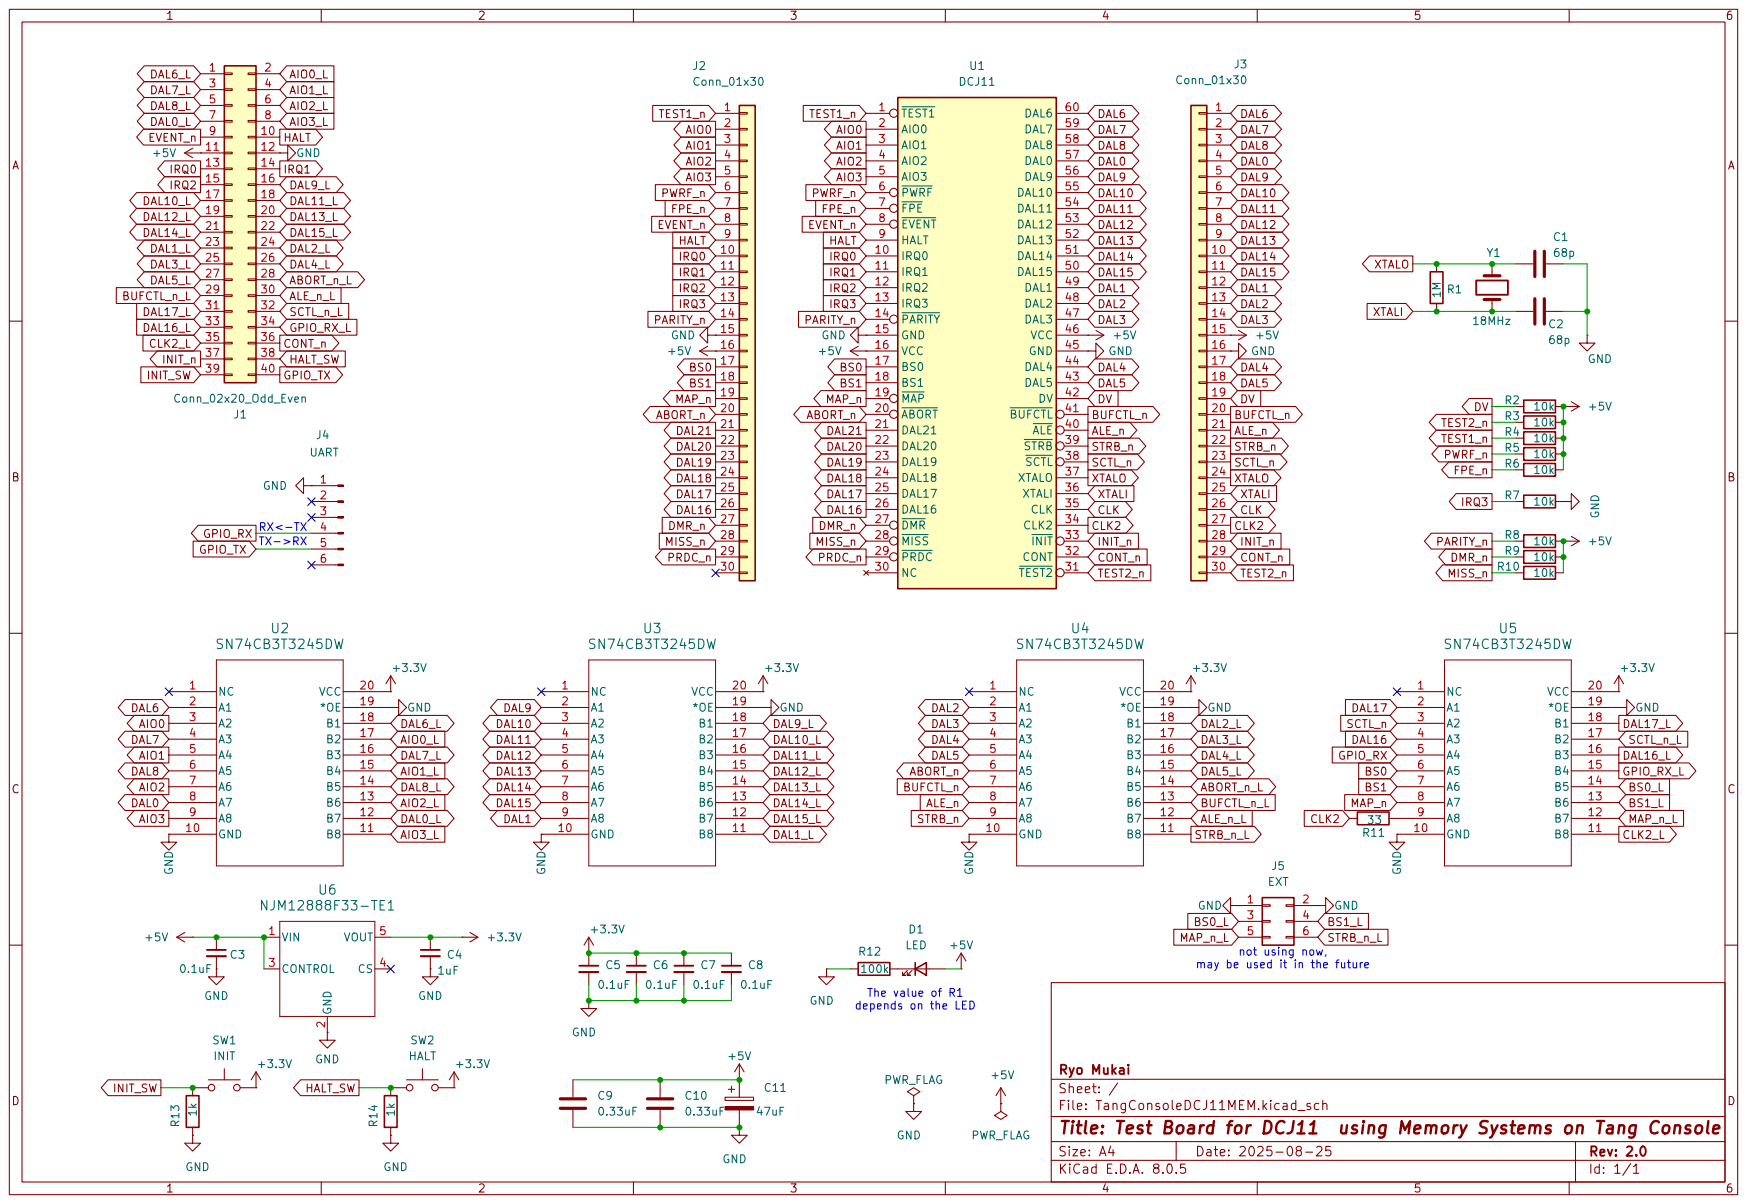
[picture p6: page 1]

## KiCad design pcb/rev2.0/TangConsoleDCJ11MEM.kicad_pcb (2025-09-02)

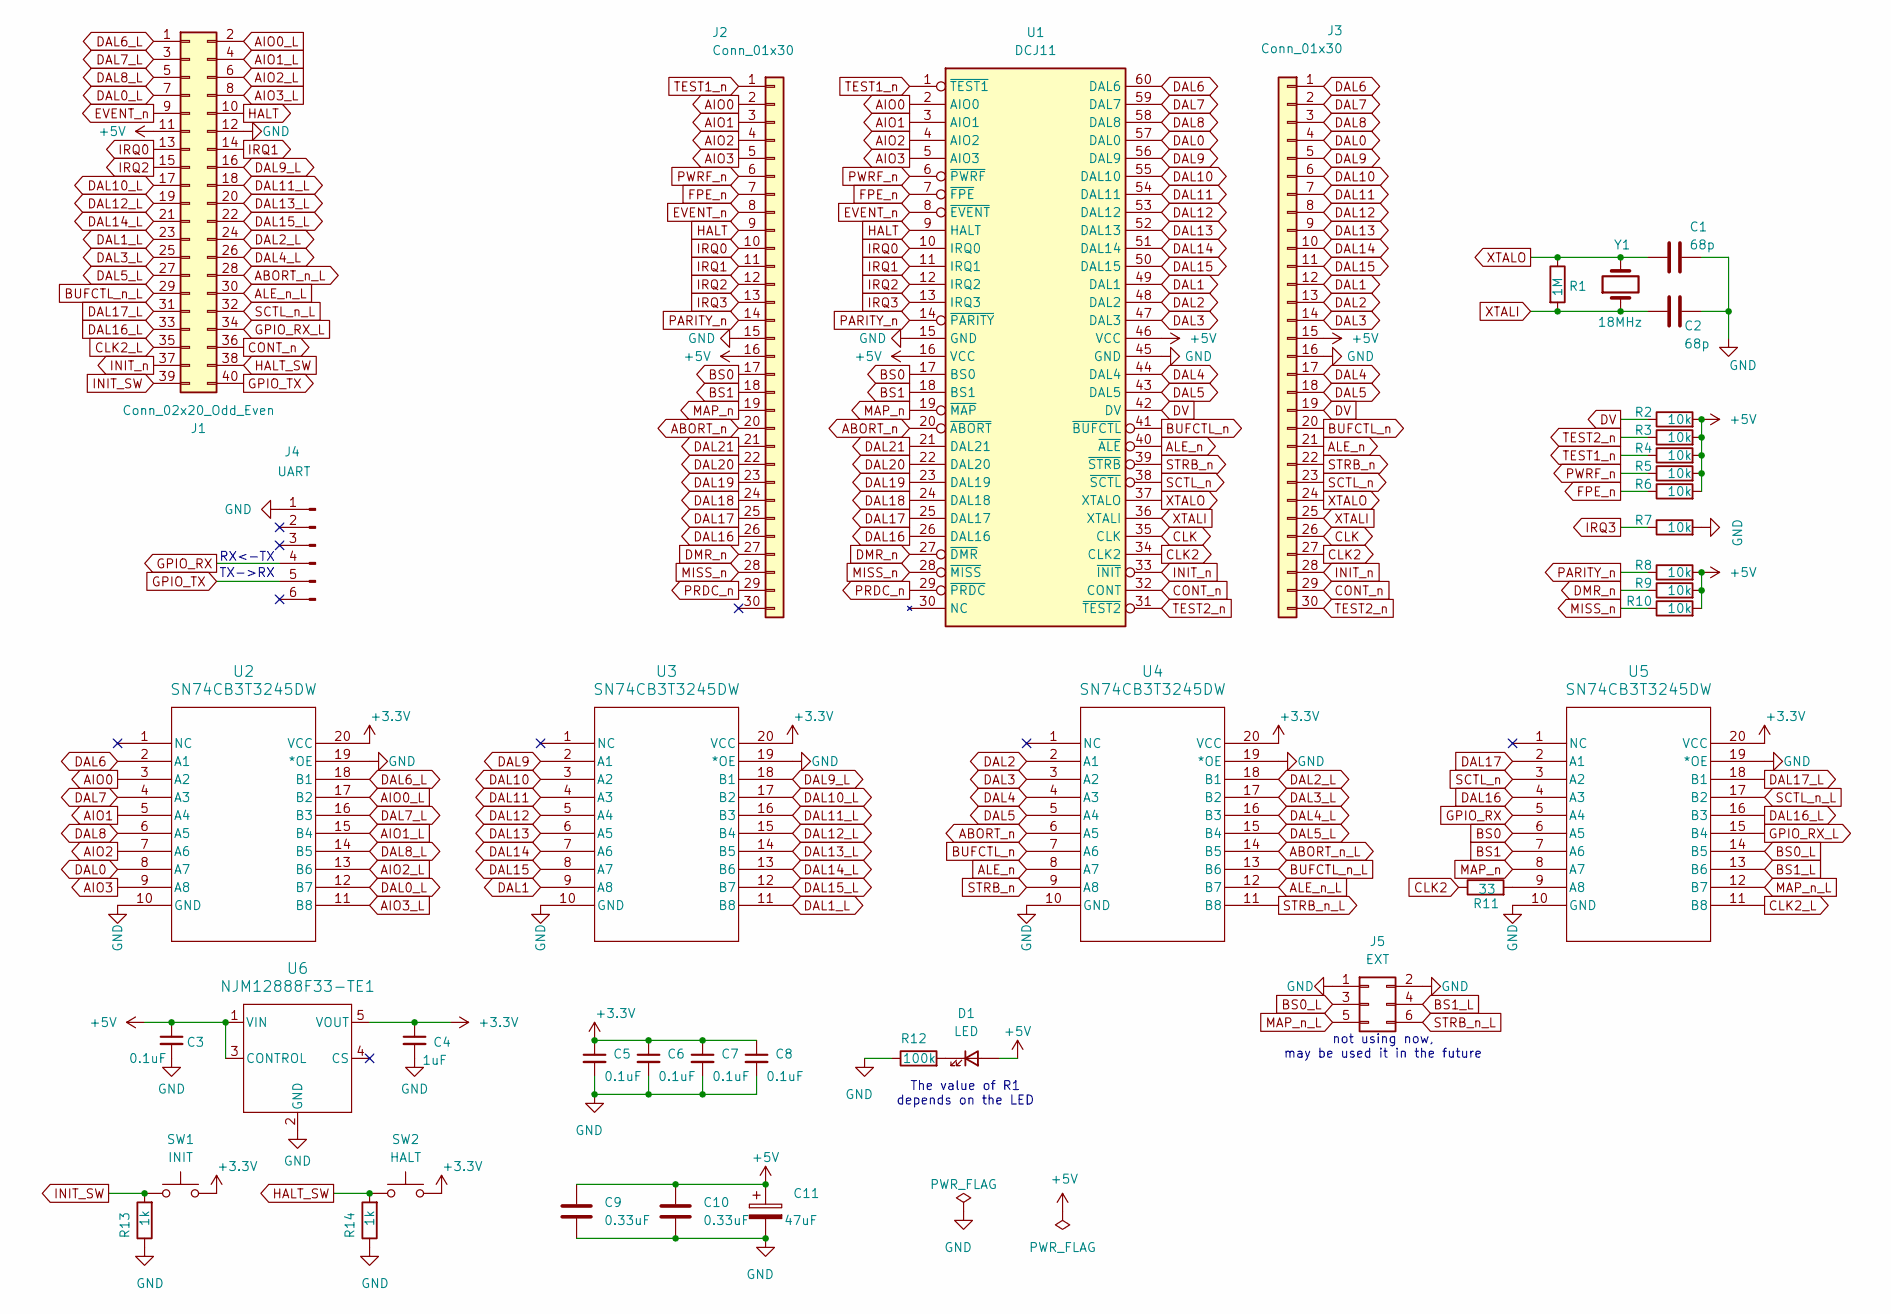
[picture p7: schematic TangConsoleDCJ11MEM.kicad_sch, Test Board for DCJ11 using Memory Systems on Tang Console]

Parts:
C1, C2: 68p; C_Disc_D5.0mm_W2.5mm_P2.50mm
C3, C5, C6, C7, C8: 0.1uF; C_Disc_D5.0mm_W2.5mm_P2.50mm
C4: 1uF; C_Disc_D4.7mm_W2.5mm_P5.00mm
C9, C10: 0.33uF; C_Disc_D5.0mm_W2.5mm_P2.50mm
C11: 47uF; CP_Radial_D6.3mm_P2.50mm
D1: LED; LED_D3.0mm
J1: Conn_02x20_Odd_Even; PinSocket_2x20_P2.54mm_Vertical
J2, J3: Conn_01x30; PinSocket_1x30_P2.54mm_Vertical
J4: UART; PinHeader_1x06_P2.54mm_Horizontal
J5: EXT; PinHeader_2x03_P2.54mm_Vertical
R1: 1M; R_Axial_DIN0207_L6.3mm_D2.5mm_P7.62mm_Horizontal
R2, R3, R4, R5, R6, R7, R8, R9, R10: 10k; R_Axial_DIN0207_L6.3mm_D2.5mm_P7.62mm_Horizontal
R11: 33; R_Axial_DIN0207_L6.3mm_D2.5mm_P7.62mm_Horizontal
R12: 100k; R_Axial_DIN0207_L6.3mm_D2.5mm_P7.62mm_Horizontal
R13, R14: 1k; R_Axial_DIN0207_L6.3mm_D2.5mm_P7.62mm_Horizontal
SW1: INIT; SW_PUSH_6mm_H4.3mm
SW2: HALT; SW_PUSH_6mm_H4.3mm
U1: DCJ11; DIP-60_W33.02mm_LongPads
U2, U3, U4, U5: SN74CB3T3245DW; DW20
U6: NJM12888F33-TE1; SOT-23-5_HandSoldering
Y1: 18MHz; Crystal_HC49-U_Vertical

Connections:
+3.3V: C4.1, C5.1, C6.1, C7.1, C8.1, SW1.2, SW2.2, U2.20 (VCC), U3.20 (VCC), U4.20 (VCC), U5.20 (VCC), U6.5 (VOUT)
+5V: C3.1, C9.1, C10.1, C11.1, D1.2 (A), J1.11, J2.16, J3.15, R2.2, R3.2, R4.2, R5.2, R6.2, R8.2, R9.2, R10.2, U1.16 (VCC), U1.46 (VCC), U6.1 (VIN), U6.3 (CONTROL)
ABORT_n: J2.20, U1.20 (~ABORT), U4.6 (A5)
ABORT_n_L: J1.28, U4.14 (B5)
AIO0: J2.2, U1.2 (AIO0), U2.3 (A2)
AIO0_L: J1.2, U2.17 (B2)
AIO1: J2.3, U1.3 (AIO1), U2.5 (A4)
AIO1_L: J1.4, U2.15 (B4)
AIO2: J2.4, U1.4 (AIO2), U2.7 (A6)
AIO2_L: J1.6, U2.13 (B6)
AIO3: J2.5, U1.5 (AIO3), U2.9 (A8)
AIO3_L: J1.8, U2.11 (B8)
ALE_n: J3.21, U1.40 (~ALE), U4.8 (A7)
ALE_n_L: J1.30, U4.12 (B7)
BS0: J2.17, U1.17 (BS0), U5.6 (A5)
BS0_L: J5.3, U5.14 (B5)
BS1: J2.18, U1.18 (BS1), U5.7 (A6)
BS1_L: J5.4, U5.13 (B6)
BUFCTL_n: J3.20, U1.41 (~BUFCTL), U4.7 (A6)
BUFCTL_n_L: J1.29, U4.13 (B6)
CLK: J3.26, U1.35 (CLK)
CLK2: J3.27, R11.1, U1.34 (CLK2)
CLK2_L: J1.35, U5.11 (B8)
CONT_n: J1.36, J3.29, U1.32 (CONT)
DAL0: J3.4, U1.57 (DAL0), U2.8 (A7)
DAL0_L: J1.7, U2.12 (B7)
DAL1: J3.12, U1.49 (DAL1), U3.9 (A8)
DAL1_L: J1.23, U3.11 (B8)
DAL2: J3.13, U1.48 (DAL2), U4.2 (A1)
DAL2_L: J1.24, U4.18 (B1)
DAL3: J3.14, U1.47 (DAL3), U4.3 (A2)
DAL3_L: J1.25, U4.17 (B2)
DAL4: J3.17, U1.44 (DAL4), U4.4 (A3)
DAL4_L: J1.26, U4.16 (B3)
DAL5: J3.18, U1.43 (DAL5), U4.5 (A4)
DAL5_L: J1.27, U4.15 (B4)
DAL6: J3.1, U1.60 (DAL6), U2.2 (A1)
DAL6_L: J1.1, U2.18 (B1)
DAL7: J3.2, U1.59 (DAL7), U2.4 (A3)
DAL7_L: J1.3, U2.16 (B3)
DAL8: J3.3, U1.58 (DAL8), U2.6 (A5)
DAL8_L: J1.5, U2.14 (B5)
DAL9: J3.5, U1.56 (DAL9), U3.2 (A1)
DAL9_L: J1.16, U3.18 (B1)
DAL10: J3.6, U1.55 (DAL10), U3.3 (A2)
DAL10_L: J1.17, U3.17 (B2)
DAL11: J3.7, U1.54 (DAL11), U3.4 (A3)
DAL11_L: J1.18, U3.16 (B3)
DAL12: J3.8, U1.53 (DAL12), U3.5 (A4)
DAL12_L: J1.19, U3.15 (B4)
DAL13: J3.9, U1.52 (DAL13), U3.6 (A5)
DAL13_L: J1.20, U3.14 (B5)
DAL14: J3.10, U1.51 (DAL14), U3.7 (A6)
DAL14_L: J1.21, U3.13 (B6)
DAL15: J3.11, U1.50 (DAL15), U3.8 (A7)
DAL15_L: J1.22, U3.12 (B7)
DAL16: J2.26, U1.26 (DAL16), U5.4 (A3)
DAL16_L: J1.33, U5.16 (B3)
DAL17: J2.25, U1.25 (DAL17), U5.2 (A1)
DAL17_L: J1.31, U5.18 (B1)
DAL18: J2.24, U1.24 (DAL18)
DAL19: J2.23, U1.23 (DAL19)
DAL20: J2.22, U1.22 (DAL20)
DAL21: J2.21, U1.21 (DAL21)
DMR_n: J2.27, R9.1, U1.27 (~DMR)
DV: J3.19, R2.1, U1.42 (DV)
EVENT_n: J1.9, J2.8, U1.8 (~EVENT)
FPE_n: J2.7, R6.1, U1.7 (~FPE)
GND: C1.1, C2.1, C3.2, C4.2, C5.2, C6.2, C7.2, C8.2, C9.2, C10.2, C11.2, J1.12, J2.15, J3.16, J4.1, J5.1, J5.2, R7.2, R12.1, R13.1, R14.1, U1.15 (GND), U1.45 (GND), U2.10 (GND), U2.19 (*OE), U3.10 (GND), U3.19 (*OE), U4.10 (GND), U4.19 (*OE), U5.10 (GND), U5.19 (*OE), U6.2 (GND)
GPIO_RX: J4.4, U5.5 (A4)
GPIO_RX_L: J1.34, U5.15 (B4)
GPIO_TX: J1.40, J4.5
HALT: J1.10, J2.9, U1.9 (HALT)
HALT_SW: J1.38, R14.2, SW2.1
INIT_SW: J1.39, R13.2, SW1.1
INIT_n: J1.37, J3.28, U1.33 (~INIT)
IRQ0: J1.13, J2.10, U1.10 (IRQ0)
IRQ1: J1.14, J2.11, U1.11 (IRQ1)
IRQ2: J1.15, J2.12, U1.12 (IRQ2)
IRQ3: J2.13, R7.1, U1.13 (IRQ3)
MAP_n: J2.19, U1.19 (~MAP), U5.8 (A7)
MAP_n_L: J5.5, U5.12 (B7)
MISS_n: J2.28, R10.1, U1.28 (~MISS)
unnamed: D1.1 (K), R12.2
unnamed: R11.2, U5.9 (A8)
PARITY_n: J2.14, R8.1, U1.14 (~PARITY)
PRDC_n: J2.29, U1.29 (~PRDC)
PWRF_n: J2.6, R5.1, U1.6 (~PWRF)
SCTL_n: J3.23, U1.38 (~SCTL), U5.3 (A2)
SCTL_n_L: J1.32, U5.17 (B2)
STRB_n: J3.22, U1.39 (~STRB), U4.9 (A8)
STRB_n_L: J5.6, U4.11 (B8)
TEST1_n: J2.1, R4.1, U1.1 (~TEST1)
TEST2_n: J3.30, R3.1, U1.31 (~TEST2)
XTALI: C2.2, J3.25, R1.2, U1.36 (XTALI), Y1.1
XTALO: C1.2, J3.24, R1.1, U1.37 (XTALO), Y1.2

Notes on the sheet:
TX->RX
RX<-TX
The value of R1 depends on the LED
not using now, may be used it in the future

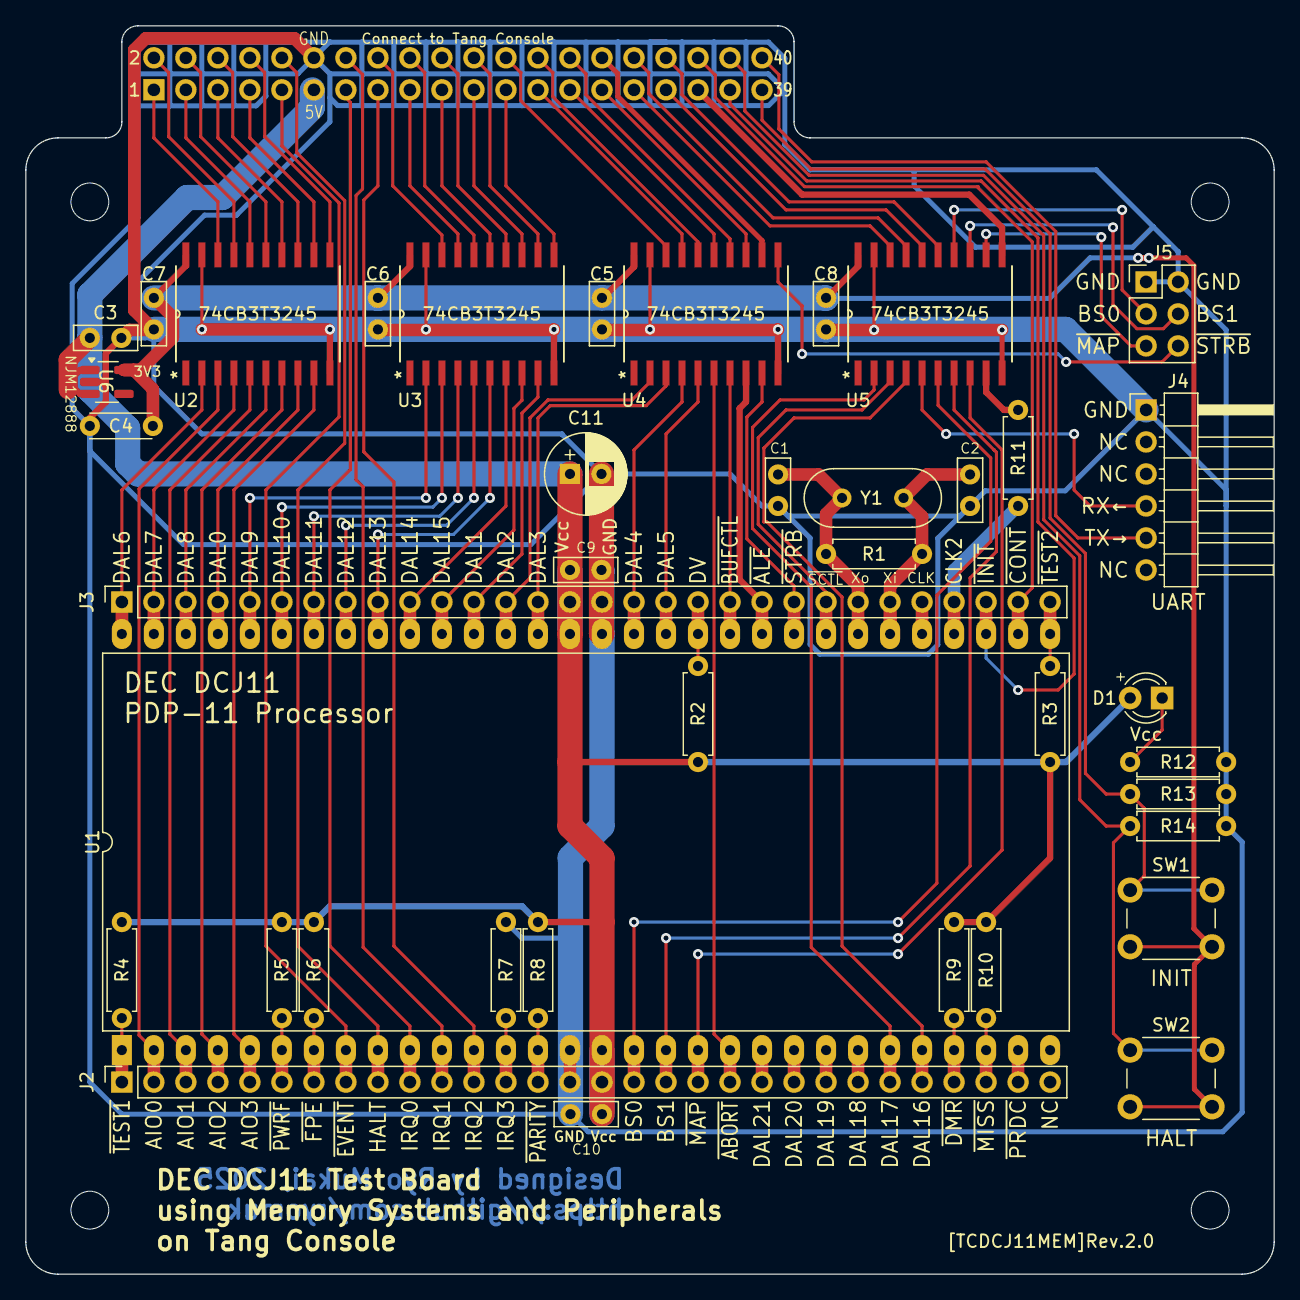
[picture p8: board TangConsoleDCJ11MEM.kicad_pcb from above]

Board: 2 copper layers, 99.1 x 99.1 mm, 40 parts (1 on the bottom side), 96 nets.

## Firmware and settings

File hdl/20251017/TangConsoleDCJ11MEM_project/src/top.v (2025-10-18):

//---------------------------------------------------------------------------
// TangConsoleDCJ11MEM
// Memory system and peripherals on Tang Console 138K for DEC DCJ11 (PDP11)
//
// version 20251017
//---------------------------------------------------------------------------
`define VERSION_ID 32'h251017_01
`define USE_ACCESSLOG            // enable disk access log for debug
`define USE_MT_WRITE_PROTECT     // write protect magnetic tape on sd2

//`define USE_RT11V4_WORKAROUND  // uncomment this line to boot RT-11 v4
  
//---------------------------------------------------------------------------
// Implemented devices
// - KL11 TTY
// - KW11-L line time clock
// - KE11-A extended arithmetic unit
// - PC11 Paper Tape read/punch
// - RF11(drum) controller
// - RK11(disk) controller
// - RP11 controller with RP03 disk pack
// - TM11 Magnetic Tape (simple read/write function only)
//
// 2025/09/02: - Ported from Tang Nano 20K to Tang Console 138K
//             - Use CLK2 as a system clock
//             - Physical memory space extended from 16bit to 18bit
//
// 2025/09/07: - Some debug tool installed
// 2025/09/11: - WS2812 installed
// 2025/09/17: - Bugfix for using without SD memory
// 2025/09/19: - PC-11(Paper-Tape Reader/Punch) emulator implemented
//             - The punch function is disabled to prevent overwriting
//             - the SD card.
// 2025/09/22: - sw2_toggle and sw2_count installed for debug
// 2025/09/25: - Onboard sw's function changed
// 2025/09/26: - Invoke IRQ_ttyo at 60Hz (dirty workaround to boot RT-11)
// 2025/10/01: - Bugfix for disks
// 2025/10/02: - RP11 controller (with RP03) emulator implemented
// 2025/10/06: - TM11/TU10 magnetic tape emulator implemented
//             - Reset by GP (RESET instruction)  implemented
//             - Boot address changed (see rom.v)
// 2025/10/08: - Disk and magtape bugfix
// 2025/10/12: - SD_MEM_FRQ changed from 400kHz to 800kHz
//             - Make read MTSC1(772440) invoke bus error (for uv7 tape boot)
// 2025/10/13: - TM11: Space forward implemented
// 2025/10/14: - TM11: interrupt on 'write IE and no GO' implemented
// 2025/10/16: - Image size for RP03 changed (for 2.9BSD's sys/conf/ioconf.c)
//             - RT-11 causes MTSC1 buserror, so compile flag
//             - 'USE_RT11V4_WORKAROUND' added.
//             - '60Hz IRQ_ttyo' disabled, 'USE_RT11V4_WORKAROUND' enables it.
//             - Compile flag 'USE_MT_WRITE_PROTECT' to avoid overwrite tape
// 2025/10/17: - SD_MEM_FRQ changed from 800kHz to 1MHz
//---------------------------------------------------------------------------
// TangNanoDCJ11MEM 
// Memory system and peripherals on TangNano20K for DEC DCJ11 (PDP11)
//
// version 20240730.v6.beta
// test version for UNIX V6 experiments
//
// by Ryo Mukai (https://github.com/ryomuk)
//
// The emulatior of the following peripherals are implemented
// for running the UNIX first edition (UNIX V1).
// - KL11 TTY
// - RF11 drum
// - RK11 disk
// - KW11-L line time clock
// - KE11-A extended arithmetic unit
//
// 2024/06/09: - Hard disk (RF11 and RK11) emulator (sdhd.v) implemented
// 2024/06/10: - KW11-L emulator implemented
// 2024/06/11: - KE11-A emulator implemented
// 2024/06/24: - initial version (very unstable)
// 2024/07/10: - separate command reception for RF11 and RK11
// 2024/07/13: - IRQ bug fixed
// 2024/07/14: - debug register address changed
// 2024/07/15: - Stretched cycle installed for RF, RK, RE11
//               - CONT_n is assigned to LED3.
//             - IRQ2 and IRQ3 are removed. LED2_n is free.
//             - Memory sytem modified to single port RAM
// 2024/07/19: - Relatively stable compared to previous versions.
// 2024/07/27: - Stabilized disk ready logic for IRQ_RFRK (dirty workaround)
//             - Bufferd TX (uart.v) implemented
//             - Some features for UNIX V6 Experiments
//               - ABORT_n installed (pin is LED[2]_n)
//                 write to 160000-167777 or read 177700 causes bus error
//               - Make RAM 28KW (160000-177777 is a ROM area)
//               - boot from RK0 disk (174000g)
// 2024/07/28: - read 160000-160077 causes bus error
// 2024/07/29: - ABORT_n changed to tri-state
//             - bus error condition changed
//                 read 170000-170077 or 177700 causes bus error
// 2024/07/30: - multiple RK disks supported
//---------------------------------------------------------------------------

module top(
    input	  sw1_n,
    input	  sw2_n,
    input	  sys_clk50, // 50MHz system clock

    input	  USB_RX,
    output	  USB_TX,

    output	  GPIO_TX,
    input	  GPIO_RX,
    output	  LOG_TX,    // disk access log for debug

    output	  sd_clk,
    output	  sd_mosi, 
    input	  sd_miso,
    output	  sd_cs_n,
    input	  sd_det_n,  //  seems not working
	   
    output	  sd2_clk,
    output	  sd2_mosi, 
    input	  sd2_miso,
    output	  sd2_cs_n,
    input	  sd2_det_n,
	   
    inout [15:0]  DAL,
    input [17:16] DALH,	     // DAL[17:16] is input (not inout)
    input [3:0]	  AIO,
//    input [1:0]	  BS,
    output	  IRQ0,
    output	  IRQ1,
    output	  IRQ2,
    inout	  ABORT_n,
    output	  EVENT_n,
    output	  INIT_n,    // CPU reset signal
    input	  BUFCTL_n,
    input	  ALE_n,
    input	  SCTL_n,
    output	  CONT_n,
    output	  HALT,
    input	  CLK2,
	   
    input	  INIT_SW,
    input	  HALT_SW,

    output	  led_b,
    output	  led_r,
    output	  LED_RGB

//    output [3:0]  dbg
    );
//---------------------------------------------------------------------------
// some configurations
//---------------------------------------------------------------------------
`ifdef USE_RT11V4_WORKAROUND
  wire flag_rt11_workaround = 1'b1;
`else
  wire flag_rt11_workaround = 0;
`endif

//---------------------------------------------------------------------------
// Clock signals
//---------------------------------------------------------------------------
  // CLK2 as a system clock
  parameter	 SYS_CLK_FRQ  = 18_000_000; //Hz
  wire		 sys_clk      = CLK2;

  // CPU clock stops while INIT, 
  // so another clock is required for the initialization
  parameter	 INIT_CLK_FRQ = 50_000_000; // Hz
  wire		 init_clk     = sys_clk50;  // system clock for reset

  reg		 sys_clk25 = 0;
  always@(posedge sys_clk50)
    sys_clk25 <= ~sys_clk25;
  
  // clock for sdhd and sdtape
  parameter	 SD_SYS_FRQ   = SYS_CLK_FRQ;
  parameter	 SD_MEM_FRQ   =1000_000;
//  parameter	 SD_MEM_FRQ   = 800_000;
//  parameter	 SD_MEM_FRQ   = 400_000;
  wire		 sd_sys_clk   = sys_clk;

  // clock for ws2812 RGB LED
  parameter      WS2812_CLK_FRQ = 50_000_000; // Hz
  wire		 ws2812_clk     = sys_clk50;
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

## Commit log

2025-09-22 folder name changed
    [device.cfg]
2025-09-22 20250922 pre-released
    [device.cfg]
2025-09-26 20250926 released
    [device.cfg]
2025-10-23 J4 was not displayed in the BOM, so I fixed it.
